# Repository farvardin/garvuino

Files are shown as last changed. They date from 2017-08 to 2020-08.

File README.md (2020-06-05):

# Garvuino 

The Garvuino is a PCB board for creating music, sounds and chiptunes, either through programming, soundtracker or live recording (midi).

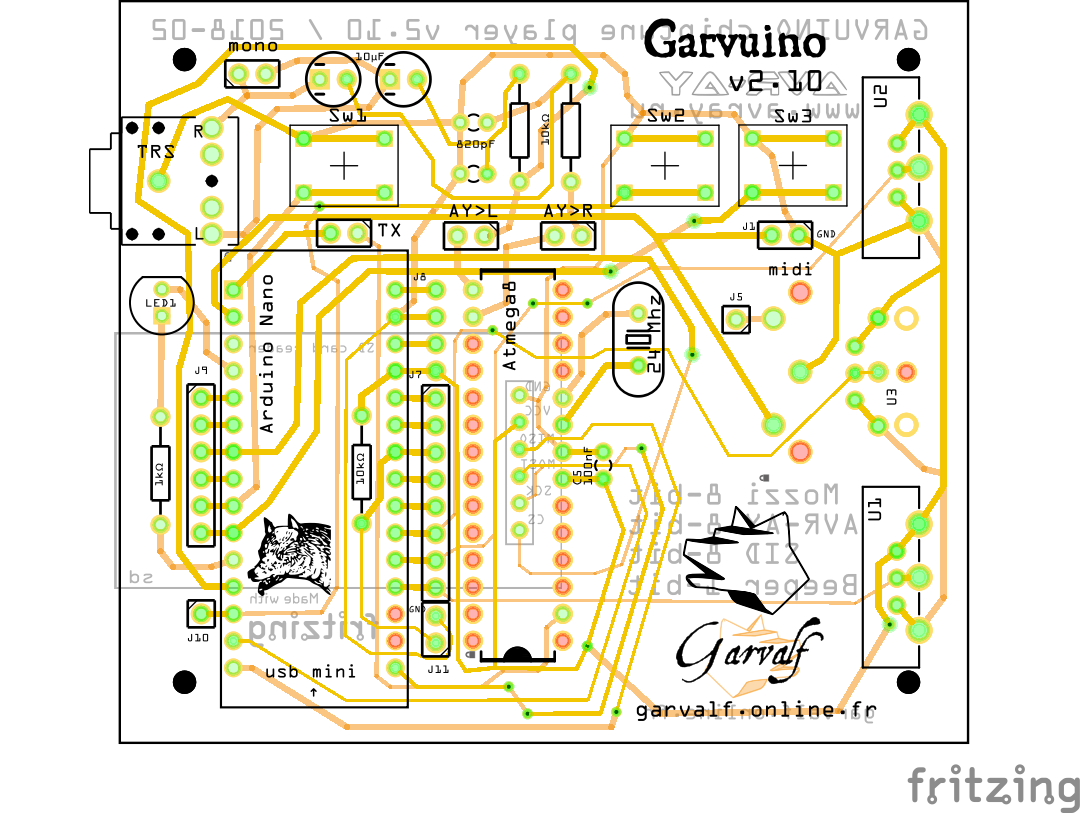
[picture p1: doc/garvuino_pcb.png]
 

It works with an Arduino Nano and an Atmega8 chip.

## Manual 

You can find the full manual [here](doc/garvuino_manual.md).

## Features 

 * AY-3-8910 emulator (using an atmega8 chip): it can replay Sinclair ZX Spectrum, Atari ST, Amstrad square wave chiptunes from the sd card.
 * Sid emulator: play some C64 musics, or use it as a midi synth with a fat sound.
 * 1-bit music: play beeper music. 
 * Mozzi synth: fun FM sounds and many other effects, driven by MIDI or some captors.

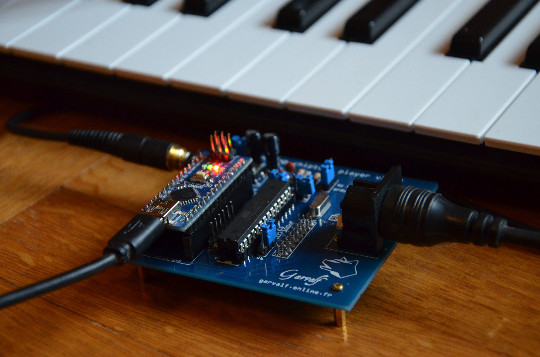
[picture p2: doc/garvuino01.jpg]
  

## How does it sound? 

### AVRAY 

 * http://picosong.com/HUGM/ (Xenon / Spectrum)
 * http://picosong.com/wseMn/ (Cauldron / Amstrad)
 * http://battleofthebits.org/arena/Entry/Underground+Water/26509/
 * https://www.youtube.com/watch?v=gzpGbokxwZ4
 * *more to come*

### Mozzi 

 * http://picosong.com/wR2RN (polydrums)
 * http://picosong.com/wR2Rr (cheap FM)
 * *more to come*

### SID emulator 

 * https://soundcloud.com/memento-somniare/sidarduino-test
 * *more to come*

### Beeper 

 * http://garvalf.online.fr/index.php?page=blog_2017-02-12
 * *more to come*

## Atmega8 setup 

Please refer to the [manual](doc/garvuino_manual.md) and [this folder](atmega8) for more info about setting up the atmega8 chip.

## PCB 

Please refer to [this folder](pcb) for the fritzing sources and gerber files.

## Breadboard 

It can also work without the PCB. Just use a breadboard and a few wires!

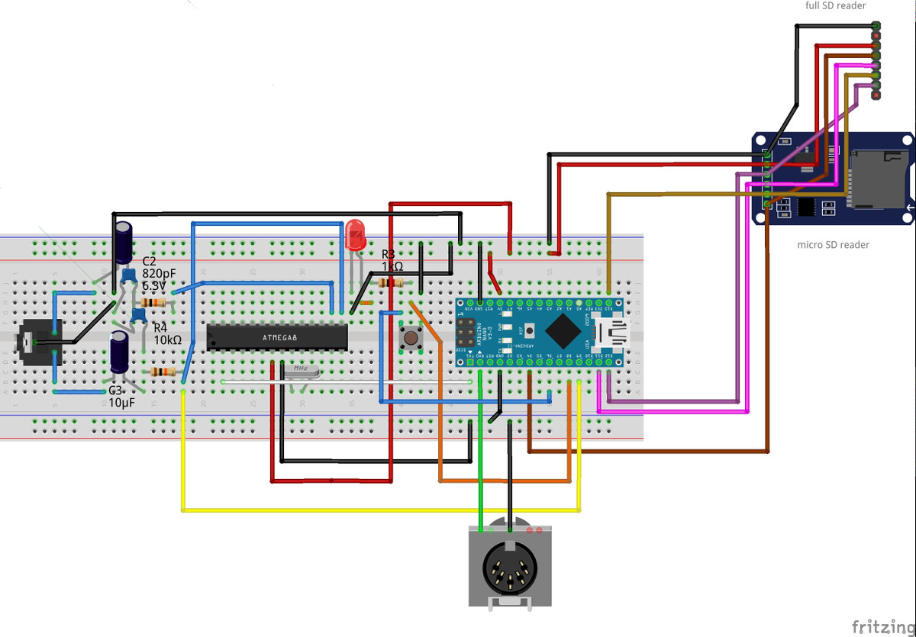
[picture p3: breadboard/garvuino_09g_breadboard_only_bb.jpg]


Please refer to [this folder](breadboard) for the fritzing sources and pdf version.

## Arduino sketches 

Get the sketches [in this folder](arduino_sketches/)

You can find [some tunes for using with the AVR-AY setup in here](tunes/). The arduino sketch can read the RSF files from the SD (it can't read the YM or AY files directly). You can convert to RSF with the [AVR-AY Player](http://www.avray.ru/avr-ay-player/).

## Links 

 * http://avray.ru/
 * http://playground.arduino.cc/Main/SID-emulator
 * http://randomflux.info/1bit/viewforum.php?id=5
 * https://sensorium.github.io/Mozzi
 * http://risgk.github.io/
 * https://github.com/dzlonline/the_synth
 * https://github.com/ArminJo/Talkie (not included in this repo, but works)

## Credits 

 * Yoruk for his help on the PCB
 * Evgeniy for AVR-AY emulator and invaluable help (initial code by Ramiros)
 * Klaud for help with avr-ay
 * Shiru for the 1-bit engines on Arduino
 * Christoph Haberer and Mario Patino for the Sid-arduino lib
 * The Mozzi team
 * Protodome for the Micro Music Macro Language (μMML) (https://github.com/protodomemusic/mmml) 

## Licence 

This BSD licence is only for the PCB sketch rendition, and code written from scratch. 
Code derived from other projects retains the original licence.
For example Avray is GPLv3.

    BSD 3-Clause License
    Copyright (c) 2015-2017, Garvalf
    All rights reserved.
    
    Redistribution and use in source and binary forms, with or without
    modification, are permitted provided that the following conditions are met:
        * Redistributions of source code must retain the above copyright
          notice, this list of conditions and the following disclaimer.
        * Redistributions in binary form must reproduce the above copyright
          notice, this list of conditions and the following disclaimer in the
          documentation and/or other materials provided with the distribution.
        * Neither the name of the <organization> nor the
          names of its contributors may be used to endorse or promote products
          derived from this software without specific prior written permission.
    
    THIS SOFTWARE IS PROVIDED BY THE COPYRIGHT HOLDERS AND CONTRIBUTORS "AS IS" AND
    ANY EXPRESS OR IMPLIED WARRANTIES, INCLUDING, BUT NOT LIMITED TO, THE IMPLIED
    WARRANTIES OF MERCHANTABILITY AND FITNESS FOR A PARTICULAR PURPOSE ARE
    DISCLAIMED. IN NO EVENT SHALL <COPYRIGHT HOLDER> BE LIABLE FOR ANY
    DIRECT, INDIRECT, INCIDENTAL, SPECIAL, EXEMPLARY, OR CONSEQUENTIAL DAMAGES
    (INCLUDING, BUT NOT LIMITED TO, PROCUREMENT OF SUBSTITUTE GOODS OR SERVICES;
    LOSS OF USE, DATA, OR PROFITS; OR BUSINESS INTERRUPTION) HOWEVER CAUSED AND
    ON ANY THEORY OF LIABILITY, WHETHER IN CONTRACT, STRICT LIABILITY, OR TORT
    (INCLUDING NEGLIGENCE OR OTHERWISE) ARISING IN ANY WAY OUT OF THE USE OF THIS
    SOFTWARE, EVEN IF ADVISED OF THE POSSIBILITY OF SUCH DAMAGE.

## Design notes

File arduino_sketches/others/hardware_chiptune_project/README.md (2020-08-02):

## Create chiptunes for the Arduino

This project is based on the "Hardware Chiptune Project" by Kryo (Linus Åkesson) : https://www.linusakesson.net/hardware/chiptune.php

It was ported to Arduino by Stimmer: 
- https://forum.arduino.cc/index.php/topic,44907.0.html

And "Bearbone" made a converter so you can create your own tunes with Kryo's original Tracker (see below):

- http://bearborne.blogspot.com/2011/12/hi-everyone-today-im-back-again-with.html
- https://www.instructables.com/id/Arduino-Chiptunes/

You can run the "kryo_hcp_org.ino" sketch, which is roughly the original port by Stimmer (and should sound close to the original tune)

The audio output is PIN 3.

## Tracker:

you can compile the sources for the tracker (on Linux), in the src folder. The "tracker" binary is provided as well (originally found in Kryo's archive)
Instructions for using the tracker can be found in README-tracker.txt

You can use my makefile to help convert the data to arduino.

The original instructions for the converter are:

- Use the tracker (Linux) to compose it.
- Export it ("%" key in the tracker).
- Run the conversion script in the tracker folder (you'll need gcc and java for it to run!).
- Open the file "song.lst" and copy its contents to the clipboard.
- Open the player sketch and replace the byte sequence in "songdata" by the sequence from "song.lst"
- Update the defines of "MAXTRACK" and "SONGLEN" to the values found in "exported.h" in the tracker directory.
- Connect a speaker to port 3 and two LEDs to ports 8 and 13 and enjoy your personal disco with synchronized light show.

Except for the "MAXTRACK" and "SONGLEN", and for connecting the speaker, the makefile should handle everything else!

For French users, you'd better switch to qwerty (done in the makefile). Non-azerty users should remove the "setxkbmap fr" in the makefile.

You can change instruments with the two keys right to the "P" key.
You can change patterns with the two keys right to the "P" key (use SHIFT in addition).
You can save your work with Ctrl+w (the key left to the "E" key)
You can export your work with % (shift+5)

More info on http://bearborne.blogspot.com/2012/02/lft-tracker-howto.html

Change your working document in the makefile, and use "make edit" to open it with the tracker, "make convert" to generate the "hardware_chiptune_project.ino" (arduino requires the .ino file to have the same name as the containing folder). "make backup" is a conveniant way to save a snapshot of your current work, in the backups folder.

Important: you might need to optimise the song (press # in the editor, shift+3) before exporting it (%), otherwise the song might not be correctly converted.

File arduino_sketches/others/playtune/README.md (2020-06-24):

## Playtune and Miditones for Arduino 

This library is an adapted version of 

 * https://github.com/LenShustek/arduino-playtune
 * https://github.com/lenshustek/miditones

They were copied and adapted for the Garvuino device:

 * https://github.com/farvardin/garvuino/

## Compile and use Miditones 

To compile miditones, just enter the "miditones" folder and type:

    make binaries

Then you can put your midifiles into this folder, edit the makefile 
(don't happend .mid at the end of the file declaration), and can type 
`make tone` to produce a .c file which you can use with playtune. 

## Playtune 

Import Playtune as a new library from your Arduino IDE.

You can use the .c file from above, or type `make ino` and it will 
provide a file you can paste or load in the Arduino IDE 
(it works great in my Arduino Uno).

## Wiring to your Arduino 

To hear the music, you have to wire a headphone or speaker to the pins 5, 6 and 9 
of your arduino (link the 3 pins together, on a breadboard for example), 
and the other end of your speaker to a ground pin. 

In addition you can add a resistor (300 or 600 ohm for ex.) to reduce some high frequencies.

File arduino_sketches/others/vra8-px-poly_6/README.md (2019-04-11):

# Digital Synth VRA8-Px v2.0.1

- 2017-07-22 ISGK Instruments
- <https://github.com/risgk/digital-synth-vra8-p/tree/vra8-px-v2>

## Concept

- 3 Voice Paraphonic Synthesizer for Arduino Uno
- A Variant of Digital Synth VRA8-P <https://github.com/risgk/digital-synth-vra8-p>

## History

### v2.0 New Features

- ORGAN Waveform Deleted, RESONANCE Steps Changed (17 -> 9)
- CC# of AMP EG, VELOCITY SENS, and CUTOFF V SENS Changed
- Improved Sound, New PRESETs, PITCH BEND Support, TRANSPOSE Support, MIDI Shield Official Support
- DETUNE S&H AMT, DETUNE EG AMT, PORTAMENTO, UNI TO MONO, CUTOFF NG AMT, EG ATTACK, AMP EG/HOLD

### v1.2 New Features

- Cutoff Velocity Sensitivity, Detune EG Amount

### v1.0 New Features

- Phase Resolution: 24 bit, Internal Signal Processing: 16 bit
- Audio Output (8 bit) with Error Diffusion, Sub Oscillators (Triangle Wave)
- Changeable Osc 2 (Detune) Level, Resonance with Q = 11.3 (Max), Velocity Sensitivity

## Features

- 3 Voice Paraphonic Synthesizer (Pseudo Polyphonic Synthesizer), MIDI Sound Module
- Serial MIDI In (38400 bps), PWM Audio Out (Pin 6), PWM Rate: 62500 Hz
    - We recommend adding a RC filter circuit to reduce PWM ripples
    - A cutoff frequency 10.6 kHz (R: 150 ohm, C: 100 nF) works well
    - A cutoff frequency 15.9 kHz (R: 100 ohm, C: 100 nF) works well, too
    - **CAUTION**: Click sounds may occur when you connect the audio out to an amp/a speaker or reset the board
    - **CAUTION**: The Arduino PWM audio output is a unipolar LINE OUT
        - Please connect this to a power amp/a headphone amp (not to a speaker/a headphone directly)
- Sampling Rate: 15625 Hz, Bit Depth: 8 bit, LPF Attenuation Slope: -12 dB/oct
- Recommending [Hairless MIDI<->Serial Bridge](http://projectgus.github.io/hairless-midiserial/) to connect PC
- Files
    - `DigitalSynthVRA8Px.ino` is a sketch for Arduino/Genuino Uno
    - `make-sample-wav-file.cc` is for Debugging on PC
        - Requiring GCC (G++) or other
        - `make-sample-wav-file-cc.bat` makes a sample WAV file (working on Windows)
    - `generate-*.rb` generate source files
        - Requiring a Ruby execution environment
- **CAUTION**: We recommend Arduino IDE 1.8.3

## VRA8-Px CTRL

- Parameter Editor (MIDI Controller) for VRA8-Px, Web App
- We recommend Google Chrome, which implements Web MIDI API
- VRA8-Px CTRL includes PRESET programs
- Recommending [loopMIDI](http://www.tobias-erichsen.de/software/loopmidi.html) (virtual loopback MIDI cable) to connect VRA8-Px
- **CAUTION**: Low CUTOFF with high RESONANCE can damage the speakers

## Controllers

    +----------------+------+----------------+---------------+----------------+------------------------------+
    | Controller     | INIT | Value 0        | Value 64      | Value 127      | Notes                        |
    +----------------+------+----------------+---------------+----------------+------------------------------+
    | UNISON/MIX     | 0    | OFF            | ON            | ON             | 3 Voice UNISON               |
    |                |      | +70.7%/+70.7%  | +70.7%/-70.7% | +70.7%/+70.7%  | Main/DETUNE MIX Level        |
    | WAVEFORM/SUB   | 0    | SAWtooth       | SQuare        | SQuare         | WAVEFORM                     |
    |                |      | 100%           | 0%            | 100%           | SUB Osc Level                |
    | DETUNE         | 48   | 0.06 Hz        | 1.0 Hz        | 3.8 Hz         |                              |
    | DETUNE S&H AMT | 32   | Avg. 0         | Avg. +32      | Avg. +63.5     | S&H: 488.3 Hz (Red Noise)    |
    | DETUNE EG AMT  | 48   | -126 (EG 100%) | 0             | +125 (EG 100%) | Modulates DETUNE             |
    | PORTAMENTO     | 32   | Off            | 0.09 s/Oct    | 0.8 s/Oct      | PORTAMENTO Time              |
    | UNI TO MONO    | 0    | OFF            | ON            | ON             | Change UNISON => MONO        |
    +----------------+------+----------------+---------------+----------------+------------------------------+
    | CUTOFF         | 64   | 0.22 kHz (A3)  | 1.2 kHz       | 7.04 kHz (A8)  | Range: 4 to 124              |
    | RESONANCE      | 64   | Q = 0.7        | Q = 2.8       | Q = 11.3       | 9 steps                      |
    | CUTOFF EG AMT  | 96   | -126 (EG 100%) | 0             | +125 (EG 100%) | EnvGen Modulates CUTOFF      |
    | CUTOFF NG AMT  | 64   | Avg. -32       | 0             | Avg. +31       | NoiseGen (White) Mods CUTOFF |
    +----------------+------+----------------+---------------+----------------+------------------------------+
    | EG ATTACK      | 0    | 4 ms           | 60 ms         | 4.2 s          | EnvGen ATTACK Time           |
    | EG DECAY       | 64   | 34 ms          | 2.2 s         | Infinity       | EnvGen DECAY Time            |
    | AMP EG/HOLD    | 0    | AMP EG OFF     | AMP EG ON     | AMP EG ON      | AMP EG ON: 64-127            |
    |                |      | HOLD OFF       | HOLD ON       | HOLD OFF       | HOLD ON: 32-95               |
    +----------------+------+----------------+---------------+----------------+------------------------------+
    | VELOCITY SENS  | 0    | 0%             | 50.4%         | 100%           | Gain VELOCITY SENSitivity    |
    | CUTOFF V SENS  | 127  | -128 (V 127)   | 0 (V 127)     | +126 (V 127)   | CUTOFF Velocity SENSitivity  |
    +----------------+------+----------------+---------------+----------------+------------------------------+

## MIDI Implementation Chart

      [Paraphonic Synthesizer]                                        Date: 2017-07-22       
      Model: Digital Synth VRA8-Px    MIDI Implementation Chart       Version: 2.0.1         
    +-------------------------------+---------------+---------------+-----------------------+
    | Function...                   | Transmitted   | Recognized    | Remarks               |
    +-------------------------------+---------------+---------------+-----------------------+
    | Basic        Default          | x             | 1             |                       |
    | Channel      Changed          | x             | x             |                       |
    +-------------------------------+---------------+---------------+-----------------------+
    | Mode         Default          | x             | Mode 3        |                       |
    |              Messages         | x             | x             |                       |
    |              Altered          | ************* |               |                       |
    +-------------------------------+---------------+---------------+-----------------------+
    | Note                          | x             | 0-127         |                       |
    | Number       : True Voice     | ************* | 24-84         | (w/o TRANSPOSE)       |
    +-------------------------------+---------------+---------------+-----------------------+
    | Velocity     Note ON          | x             | o (V=1-127)   |                       |
    |              Note OFF         | x             | x             |                       |
    +-------------------------------+---------------+---------------+-----------------------+
    | After        Key's            | x             | x             |                       |
    | Touch        Ch's             | x             | x             |                       |
    +-------------------------------+---------------+---------------+-----------------------+
    | Pitch Bend                    | x             | o             | Range: 2 (or 12)      |
    +-------------------------------+---------------+---------------+-----------------------+
    | Control                    16 | x             | o             | UNISON/MIX            |
    | Change                     17 | x             | o             | WAVEFORM/SUB          |
    |                            18 | x             | o             | DETUNE                |
    |                            19 | x             | o             | CUTOFF NG AMT         |
    |                            20 | x             | o             | CUTOFF                |
    |                            21 | x             | o             | RESONANCE             |
    |                            22 | x             | o             | CUTOFF EG AMT         |
    |                            23 | x             | o             | EG DECAY              |
    |                            24 | x             | o             | EG ATTACK             |
    |                            25 | x             | o             | DETUNE S&H AMT        |
    |                            26 | x             | o             | DETUNE EG AMT         |
    |                            27 | x             | o             | AMP EG/HOLD           |
    |                            28 | x             | o             | VELOCITY SENS         |
    |                            29 | x             | o             | CUTOFF V SENS         |
    |                            30 | x             | o             | PORTAMENTO            |
    |                            31 | x             | o             | UNI TO MONO           |
    +-------------------------------+---------------+---------------+-----------------------+
    | Program                       | x             | x             |                       |
    | Change       : True #         | ************* |               |                       |
    +-------------------------------+---------------+---------------+-----------------------+
    | System Exclusive              | x             | x             |                       |
    +-------------------------------+---------------+---------------+-----------------------+
    | System       : Song Pos       | x             | x             |                       |
    | Common       : Song Sel       | x             | x             |                       |
    |              : Tune           | x             | x             |                       |
    +-------------------------------+---------------+---------------+-----------------------+
    | System       : Clock          | x             | x             |                       |
    | Real Time    : Commands       | x             | x             |                       |
    +-------------------------------+---------------+---------------+-----------------------+
    | Aux          : Local ON/OFF   | x             | x             |                       |
    | Messages     : All Notes OFF  | x             | o (123-127)   |                       |
    |              : Active Sense   | x             | x             |                       |
    |              : Reset          | x             | x             |                       |
    +-------------------------------+---------------+---------------+-----------------------+
    | Notes                         |                                                       |
    |                               |                                                       |
    +-------------------------------+-------------------------------------------------------+
      Mode 1: Omni On,  Poly          Mode 2: Omni On,  Mono          o: Yes                 
      Mode 3: Omni Off, Poly          Mode 4: Omni Off, Mono          x: No

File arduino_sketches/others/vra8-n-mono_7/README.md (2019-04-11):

# Digital Synth VRA8-N v2.0.1

- 2019-03-24 ISGK Instruments
- <https://github.com/risgk/digital-synth-vra8-n>

## Concept

- Monophonic Synthesizer (MIDI Sound Module) for Arduino Uno

## Change History

- v2.0.1
    - Fix sound quality degradation in v2.0.0
    - Revert "SUSTAIN (OFF/ON)" to "SUSTAIN"
- v2.0.0 (Major Changes)
    - Change "OSC (SAW/SQ)" to "OSC1/2 (SAW/SQ)"
    - Add "EXPRESSION", "EXP > CUTOFF", "EXP > AMP LEVEL", and "EXP BY VEL (OFF/ON)"
- v1.2.1
    - Improve sound quality
    - Improve VRA8-N CTRL compatibility between versions
- v1.2.0 (Major Changes)
    - Add "EG > PITCH(-/+)", "EG > P. TGT (1&2/2)", "RELEASE (OFF/ON)", and "EG > LFO RATE (-/+)"
    - Change "OSC2 MIX" (OSC2 Max 50%) to "OSC MIX (1/2)" (OSC2 Max 100%)
    - Change "SUB WAVE (SIN/SQ)" to "SUB (SIN/NOISE/SQ)"
    - Change "AMP (GATE+RLS/EG)" to "AMP EG (OFF/ON)" (No Release)
    - Change "SUSTAIN" to "SUSTAIN (OFF/ON)"
    - Change "LFO WAVE (TRI/SQ)" to "LFO (T/2/SA/RND/SQ)"
    - Change "LFO > PITCH (2/1+2)" to "LFO > PITCH (-/+)" and "LFO > P. TGT (1&2/2)"
    - Change "KEY ASGN (LO/LAST)" to "K. ASN (L/L/P/H/LST)"
    - Change the variation range of "CUTOFF" 7-127 to 4-124
    - Change the names of controllers
    - Change the layout and the display of VRA8-N CTRL
    - Change PRESETs
- v1.1.0 (Major Changes)
    - Add "SUB WAVE (SIN/SQ)" and "LFO WAVE (TRI/SQ)"

## Features

- Sampling Rate: 31.25 kHz, Bit Depth: 8 bit, LPF Attenuation Slope: -12 dB/oct
- Serial MIDI In (38.4 kbps), PWM Audio Out (Pin 6), PWM Rate: 62.5 kHz
    - We recommend adding a RC filter circuit to reduce PWM ripples
        - A cutoff frequency 15.9 kHz (R: 100 ohm, C: 100 nF) works well
    - **CAUTION**: The Arduino PWM audio output is a unipolar Line Out
        - Please connect this to a power amp/a headphone amp (not to a speaker/a headphone directly)
    - **CAUTION**: Click sounds may occur when you connect the audio out to an amp or reset the board
- We recommend [Hairless MIDI<->Serial Bridge](http://projectgus.github.io/hairless-midiserial/) to connect PC
    - A MIDI Shield (MIDI Breakout) and a power supply adapter are desirable to avoiding USB noise
        - Edit `SERIAL_SPEED` in `DigitalSynthVRA8N.ino` to use MIDI Shield
- Files
    - `DigitalSynthVRA8N.ino` is a sketch for Arduino (Genuino) Uno Rev3
    - `make-sample-wav-file.cc` is for Debugging on PC
        - Requiring GCC (g++) or other
        - `make-sample-wav-file-cc.bat` makes a sample WAV file (working on Windows)
    - `generate-*.rb` generates source files
        - Requiring a Ruby execution environment
- **CAUTION**: We *strongly recommend* **Arduino IDE 1.8.5**
    - `DigitalSynthVRA8N.ino` *does not work well* with Arduino IDE 1.8.6 or later

## VRA8-N CTRL

- MIDI Controller (Editor) for VRA8-N, Web App
- VRA8-N CTRL converts Program Changes (#0-7 for PRESET) into Control Changes
- VRA8-N CTRL memorizes USER Programs (#8-15)
- We recommend Google Chrome, which implements Web MIDI API
- We recommend [loopMIDI](http://www.tobias-erichsen.de/software/loopmidi.html) (virtual loopback MIDI cable) to connect VRA8-N
- **CAUTION**: Low CUTOFF with high RESONANCE can damage the speakers
- **CAUTION**: Click sounds may occur when you change the control values

## Details of Controllers

- "OSC1/2 (SAW/SQ)": OSC1 Wave / OSC2 Wave
    - Values 0-15: OSC1 SAW / OSC2 SAW
    - Values 16-63: OSC1 SAW / OSC2 SQUARE
    - Values 64-111: OSC1 SQUARE / OSC2 SAW
    - Values 112-127: OSC1 SQUARE / OSC2 SQUARE
- "SUB (SIN/NOISE/SQ)": SUB Osc Wave
    - Values 0-31: SIN
    - Values 32-95: NOISE
    - Values 96-127: SQUARE
- "LFO (T/2/SA/S&H/SQ)": LFO Wave
    - Values 0-15: Triangle (Key Trigger: Off)
    - Values 16-47: Triangle 2 (Key Trigger: On)
    - Values 48-79: SAW Down (Key Trigger: On)
    - Values 80-111: RANDOM (Key Trigger: On)
    - Values 112-127: SQUARE Up (Key Trigger: On)
- "LEGATO (OFF/ON)": LEGATO Portamento
    - When LEGATO Portamento is ON, Single Trigger is forced
- "K. ASN (L/L/P/H/LST)": Key ASSIGN / Trigger Mode
    - Values 0-47: Lowest Note / Single Trigger
    - Values 48-79: Paraphonic (Lowest and Highest Notes) / Single Trigger
    - Values 80-111: Highest Note / Single Trigger
    - Values 112-127: LAST One Note / Multi Trigger
- "EXP BY VEL (OFF/ON)": EXPRESSION Control By (Note ON) VELOCITY

## A Sample Setting of a Physical Controller (8-Knob)

    +-------------------+---------------+---------------+---------------+
    | CC #16            | CC #17        | CC #23        | CC #19        |
    | CUTOFF            | RESONANCE     | ATTACK        | DECAY         |
    +-------------------+---------------+---------------+---------------+
    | CC #24            | CC #25        | CC #26        | CC #22        |
    | OSC (SAW/SQ)      | OSC MIX (1/2) | SUB LEVEL     | PORTAMENTO    |
    +-------------------+---------------+---------------+---------------+

## MIDI Implementation Chart

      [Monophonic Synthesizer]                                        Date: 2019-03-24       
      Model: Digital Synth VRA8-N     MIDI Implementation Chart       Version: 2.0.1         
    +-------------------------------+---------------+---------------+-----------------------+
    | Function...                   | Transmitted   | Recognized    | Remarks               |
    +-------------------------------+---------------+---------------+-----------------------+
    | Basic        Default          | x             | 1             |                       |
    | Channel      Changed          | x             | x             |                       |
    +-------------------------------+---------------+---------------+-----------------------+
    | Mode         Default          | x             | 3             |                       |
    |              Messages         | x             | x             |                       |
    |              Altered          | ************* |               |                       |
    +-------------------------------+---------------+---------------+-----------------------+
    | Note                          | x             | 0-127         |                       |
    | Number       : True Voice     | ************* | 0-120         |                       |
    +-------------------------------+---------------+---------------+-----------------------+
    | Velocity     Note ON          | x             | o (V=1-127)   | When EXP BY VEL is ON |
    |              Note OFF         | x             | x             |                       |
    +-------------------------------+---------------+---------------+-----------------------+
    | After        Key's            | x             | x             |                       |
    | Touch        Ch's             | x             | x             |                       |
    +-------------------------------+---------------+---------------+-----------------------+
    | Pitch Bend                    | x             | o             |                       |
    +-------------------------------+---------------+---------------+-----------------------+
    | Control                     1 | x             | o             | MODULATION DEPTH      |
    | Change                     11 | x             | o             | EXPRESSION            |
    |                               |               |               |                       |
    |                            24 | x             | o             | OSC1/2 (SAW/SQ)       |
    |                            25 | x             | o             | OSC MIX (1/2)         |
    |                            20 | x             | o             | OSC2 COARSE (-/+)     |
    |                            21 | x             | o             | OSC2 FINE (-/+)       |
    |                               |               |               |                       |
    |                            29 | x             | o             | SUB (SIN/NOISE/SQ)    |
    |                            26 | x             | o             | SUB LEVEL             |
    |                           104 | x             | o             | EG > PITCH (-/+)      |
    |                           105 | x             | o             | EG > P. TGT (1&2/2)   |
    |                               |               |               |                       |
    |                            16 | x             | o             | CUTOFF                |
    |                            17 | x             | o             | RESONANCE             |
    |                            18 | x             | o             | EG > CUTOFF (-/+)     |
    |                            31 | x             | o             | AMP EG (OFF/ON)       |
    |                               |               |               |                       |
    |                            23 | x             | o             | ATTACK                |
    |                            19 | x             | o             | DECAY                 |
    |                            27 | x             | o             | SUSTAIN               |
    |                            28 | x             | o             | RELEASE (OFF/ON)      |
    |                               |               |               |                       |
    |                            14 | x             | o             | LFO (T/2/SA/RND/SQ)   |
    |                            80 | x             | o             | LFO RATE              |
    |                            82 | x             | o             | LFO > PITCH (-/+)     |
    |                            83 | x             | o             | LFO > CUTOFF (-/+)    |
    |                               |               |               |                       |
    |                            81 | x             | o             | LFO DEPTH             |
    |                             3 | x             | o             | EG > LFO RATE (-/+)   |
    |                             9 | x             | o             | LFO > P. TGT (1&2/2)  |
    |                            15 | x             | x             | (RESERVED)            |
    |                               |               |               |                       |
    |                            85 | x             | o             | P. BEND RANGE         |
    |                            86 | x             | x             | (RESERVED)            |
    |                           106 | x             | o             | EXP > CUTOFF (-/+)    |
    |                           107 | x             | o             | EXP > AMP LEVEL       |
    |                               |               |               |                       |
    |                            22 | x             | o             | PORTAMENTO            |
    |                            30 | x             | o             | LEGATO (OFF/ON)       |
    |                            87 | x             | o             | K. ASN (L/L/P/H/LST)  |
    |                            89 | x             | o             | EXP BY VEL (OFF/ON)   |
    +-------------------------------+---------------+---------------+-----------------------+
    | Program                       | x             | o             |                       |
    | Change       : True #         | ************* | 0-7           |                       |
    +-------------------------------+---------------+---------------+-----------------------+
    | System Exclusive              | x             | x             |                       |
    +-------------------------------+---------------+---------------+-----------------------+
    | System       : Song Pos       | x             | x             |                       |
    | Common       : Song Sel       | x             | x             |                       |
    |              : Tune           | x             | x             |                       |
    +-------------------------------+---------------+---------------+-----------------------+
    | System       : Clock          | x             | x             |                       |
    | Real Time    : Commands       | x             | x             |                       |
    +-------------------------------+---------------+---------------+-----------------------+
    | Aux          : Local ON/OFF   | x             | x             |                       |
    | Messages     : All Notes OFF  | x             | o 123-127     |                       |
    |              : Active Sense   | x             | x             |                       |
    |              : Reset          | x             | x             |                       |
    +-------------------------------+---------------+---------------+-----------------------+
    | Notes                         |                                                       |
    |                               |                                                       |
    +-------------------------------+-------------------------------------------------------+
      Mode 1: Omni On,  Poly          Mode 2: Omni On,  Mono          o: Yes                 
      Mode 3: Omni Off, Poly          Mode 4: Omni Off, Mono          x: No

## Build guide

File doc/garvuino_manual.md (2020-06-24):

# Garvuino manual

Thank you for your interest in Garvuino! The Garvuino is a PCB board for creating music, sounds and chiptunes, either through programming, soundtracker or live recording (midi).

As the hardware is open-source, you can modify, hack and have fun with it without restriction.

The PCB, schematics, code and further instructions can be found on https://github.com/farvardin/garvuino/

  

## Presentation of the board 

Several modes can be used: 

### AY-3-8910 emulator 

On Atmega8 chip, driven by the Arduino nano, from the [AVR-AY project](http://avray.ru/)

 * It can replay Sinclair ZX Spectrum, Atari ST, Amstrad chiptunes from the sd card. You can create thoses chiptunes with Vortex Tracker II or Arkos Tracker.
 * It's possible to use it as a (very simple and dirty) AY soundbox, driven by some external captors (light sensor). But it might not be possible to controle it with MIDI.

### Sid emulator 

On Arduino, from the [sid emulator lib](http://playground.arduino.cc/Main/SID-emulator)

 * It can replay some sid files, from the arduino memory, which is limited (so tunes will be cut). We'd like to find a way to stream the tune from the sd card, it's probably possible.
 * It can be used as a Sid synth, driven by midi.

### 1-bit music 

From various 1-bit engines: http://randomflux.info/1bit/viewforum.php?id=5 (on arduino)

 * It can play music from the arduino memory. 1-bit music don't need much memory so a whole song, even a complex one, can fit in the memory. You can create those songs with Beepola or MilkyTracker.
 * It might be possible to stream data from SD if the 1-bit music engine chosen is the same for all the songs.
 * It might be possible to create a 1-bit synth in the future. Probably not an easy task.

### Mozzi synth 

 * [Mozzy synth](https://sensorium.github.io/Mozzi), can output fun FM sounds and many other effects.

### Hardware 

The board has 2 chips : 

 * an Arduino Nano for the compute (it is a complete board for development)
 * an optional Atmega8 for AY sound output.

A few components :
 * a 24 Mhz crystal that is driving the Atmega8
 * some capacitors and resistors to filter the output 
 * a SD card reader to read AY music files (optional)
 * a DIN5 midi input to use the board as a midi synth (optional)  



The LED is connected to D8 on Arduino. The audio output to D9. The switch to D6. On Garvuino v2.10 and expansion board, the potentiometers are connected to A0 to A1 and to A0 to A4 respectively.

More precisely:

| PIN |use|
|---------------|
|D2 |FREE|
|D3 |audio out (some sketches)|
|D4 |CS for SD card reader|
|D5 |FREE|
|D6 |switch Sw1 / audio out (some sketches)|
|D7 |switch Sw3 / audio out (playtune)||
|D8 |led1|
|D9 |audio out (most sketches)|
|D10 |switch Sw2|
|D11 |MOSI: SD card reader|
|D12 |MISO: SD card reader|
|D13 |SCK; SD card reader (onboard LED too)||
|A0 |POT 1|
|A1 |POT 2|
|A2 |POT 3|
|A3 |POT 4|
|A4 |SDA: oled display|
|A5 |SCL: oled display|
|A6 |POT 5|
|A7 |FREE|

(TODO: playtune outputs to PIN9, 5 and 6)

There are a few jumpers on the board. They are for switching between some modes.

When used in AY mode, the mono jumper should be off, when used in beeper, sid or mozzi mode the mono jumper should be on, the J4 (ay chip ground, v1.09 board only) should be off. Also the AY>L and AY>R can be off to reduce noise (but it will work anyway). And TX could be off as well when flashing the arduino chip (you can leave it on, but if the transfer fails, try to remove it)

More detailled informations about the jumpers:

 * mono: used in mozzi, 1-bit and sid mode. You can remove the jumper in AY mode because it's in stereo (but you might also prefer using the mono mode)

 * TX: used for transmitting data to the Atmega8 chip in AY mode. You can remove the jumper when not in AY mode. You can also keep it, it doesn't matter, unless you have some problem for flashing the arduino board. On some boards, the jumper is below the board for easier access to the push button.

 * AY>L and AY>R: used in AY mode. You can cut a voice if you remove the jumper. If you remove the jumper when not in AY mode, you'll be sure there won't be extra noise from the Atmega8 chip.

 * J1: extra midi input GND (below) and midi wire nb 5 if you don't want to use the DIN5 plug.

 * J2/J3: for connecting regular (big) SD reader. Most board will use the smaller SD reader

 * J4 / ay chip GND / arduino chip (v1.09 board only): ay chip used in AY mode. It's better to put the jumper in the "arduino chip" mode (bottom), when not using AY otherwise you'll get extra and residual noise from the atmega8 chip.

 * J5 (v1.09 board only): not used. Linked to midi 4 wire "just in case".

 * J6 (v1.09 board only): not used. Could be used to switch off the atmega8 but since there are still some residual noise without it, it can be kept connected. It's been soldered on most boards.

 * J7 (v1.09) / J11 (v2.10): can be used for programming the Arduino for Analog input (potentiomer, light sensor for example)

 * J8: not used. Can be connected to arduino +5V, RST, GND and VIN but shouldn't be necessary.

 * J9: can be used for programming the Arduino for digital output (more leds for example) 

 * J10: not used. Extra digital output.

 * Led: for monitoring some infos

You can of course connect audio out to the mini-jack, but it's also possible to connect a small buzzer (HP), for example 8 ohms / 1 W to the AY>L (under the L) and to the GND (for example in the middle 3-pin J4 or on the GND of J1, if it's installed) then you'll get very cheap sound. It can be useful for monitoring.

```
Midi: You can plug a DIN5 midi cable into the dedicated port. When removing it, please do it slowly, to avoid tearing everything apart. And when pluging it in and out, hold the midi port with your hand to avoid extra pressure on the connexions.
```

You can also use [hairless midi serial bridge](https://projectgus.github.io/hairless-midiserial/) (windows, mac os x, linux) or [ttymidi](http://www.varal.org/ttymidi/) (linux) to create a virtual connection going through serial port. You'll need to adjust the arduino sketch to enable this (search for hairless midi or ttymidi in the sketch, or for #define USBMIDI at the begining of the sketch).

## Flashing the Garvuino board 

This board is supposed to work extensively with the Arduino IDE (http://arduino.cc/). You must download it and use it for developping, changing sounds and engines. The only exception is if you only intend to use the board as a AY player, then you can just change the tunes on the SD card.

Programs on Arduino are called sketches. Most sketches are tested with Arduino IDE 1.8.# but they should work with IDE 1.6.#. With latest arduino IDE (1.8.9), you must select: Processor: "Atmega328 (old bootloader)".

Get the sketches from there:

https://github.com/farvardin/garvuino/archive/master.zip

For flashing, just launch the Arduino IDE, connect the arduino to your computer using an USB mini cable, select in the tools>arduino nano, atmega328(P)(old bootloader, if applicable), select the right port. 

Load a sketch from the arduino_sketches/ folder.

For flashing, you need to unplug the midi cable from your synth ir garvuino if it's connected, or powerdown the synth. If you want to develop a sketch on garvuino, it can be tiresome to always unplug the midi. You can use a simpler wire <=> midi connected to the J1, with GND to midi GND (pin 2) and the other slot (which is connected to the RXD port) to the midi pin 5, this way it's faster to unplug. Or use ttymidi or hairless midi serial to usb port (see above)

In the case you get a:

    avrdude: stk500_getsync() attempt 1 of 10: not in sync: resp=0x32

it can be from different causes. If the midi plug is connected, see advice above. But it can also appear at random occasions. I suspect it's because of some electricity in the atmega8 chip. In this case, you can remove the TX jumper (above the arduino nano). You only need it connected when playing AY chiptunes (see below).
This kind of message can also be seen if you've choosen the wrong port to connect the arduino.

### Flashing for AY music 

Just load avray/avray_sd_sketch/avray_sd_sketch.ino, put some tunes from tunes/aym_tunes/1_75MHz/rsf/ into your SD card and power the device!

If you create your own tunes (using Vortex Tracker II for example), you'll need to convert them to RSF using the AVR-AY player: http://www.avray.ru/avr-ay-player/

You can also create tunes using [Deflemask](http://deflemask.com/) (choose Master System SN76489 PSG) or [Bamboo Tracker](https://github.com/rerrahkr/BambooTracker/) (use only the SSC channels) and convert the exported VGM tunes to RSF using the vgm2rsf tool: https://github.com/farvardin/garvuino/tree/master/tools/vgm2rsf

### Sid emulator 

load /sid/sid_midi/sid_midi.ino for the Sid emulator synth. Change sound mode with the switch. You can change some sound with knobs on your keyboard. The sketch is programmed for my Behringer UMA25S keyboard, knob E09 to E13 (midi control 71 to 75).

There is also a sid player (/sid/sid_player/) which can load some SID data and play it from the arduino (at the moment it can only load from memory, which isn't big enough for a complete song).

You can also connect a gyroscope module to the Garvuino and have fun with sounds. See sid/gyro_header_sid/ for this.

### Flashing for 1-bit music 

Only one 1-bit music can be installed into the Arduino at a time. Load a sketch, for example beeper/arduino_qchan/arduino_qchan.ino and flash the Arduino. Music should go out of the mini-jack now!

You can compose music using the [beepola tracker](http://freestuff.grok.co.uk/beepola/).

Beepola can use the Tritone, Qchan and Phaser1 engines. 

There are python converters in the folder to convert your own music to arduino code. Just make it into beepola and "compile" it to .bin format in the tools menu (without song engine, "song data only"). Convert the bin to data readable by the arduino with the python script. 

Then include your code into the arduino sketch (use #include "your_song.h" instead of #include "music_data.h" for example.) Use the line that is not commented (a comment on arduino starts with with two /)

For the octode engine, you'll have to edit a .xm file with a tracker like milkytracker. See http://battleofthebits.org/lyceum/View/Octode for more informations. There is a xm to arduino converter in the arduino_octode folder as well.

Read more on the [1-bit forum thread](http://randomflux.info/1bit/viewforum.php?id=5) (search for arduino)

If you have some problem for creating your own music and exporting it to arduino, you can join the 1-bit forum to request for help.

### Flashing for Mozzi synth 

There are several examples in the mozzi/ folder, just try them out!

You can also use most mozzi examples from the original library (see Examples/Mozzi in the Arduino IDE).

### Flashing other sketches 

The Garvuino should be able to play many other sketches from various projects on internet.

#### Playtune 

Playtune can play some MIDI files after converting them. It can be found in ./arduino_sketches/others/playtune

Just connect PIN 5 to AY>L and PIN 6 to AY>R (PIN 9 is already connected to audio output) and you'll get a midi player able to play up to 3 voices. You can connect even more voices to the free Digital Output on the Garvuino (for example by adding a pin on PIN 7).

Use the playtune_nano/playtune_nano.ino sketch.

#### Auduino 

The Auduino is a project for using granular synthesis with 5 potentiometers, you'll have to connect PIN3 from the arduino to the AY>L audio output (read the sketch header for more informations).

#### "The Synth" 

"The Synth" is a project for using Arduino as a monophonic wavetables synth. 
It's lightweight and easy to hack.

You'll have to connect PIN3 from the arduino to the AY>L audio output (read the sketch header for more informations).

https://www.instructables.com/id/Turn-your-Arduino-into-a-4-voice-wavetable-synth-w/

#### Digital Synth VRA8 

VRA8 is an awesome project with several different monophonic and polyphonic synths for Arduino.

It's compatible with the Garvuino. Get more informations for how to use it on http://risgk.github.io/.

You'll have to connect PIN6 from the arduino to the AY>L audio output.

https://www.instructables.com/id/Digital-Synth-VRA8-Px-for-Arduino-Uno/

For hairless midi, get it on https://projectgus.github.io/hairless-midiserial/

On Debian based systems, to run it, you'll probably need to install libsm6, libxrender, libasound2 and libasound2-plugins (for i386):

    sudo apt install libsm6:i386 libxrender1:i386 libasound2:i386 libasound2-plugins:i386

Run the arduino sketch (using the 1.8.5 or below IDE for example). Close Arduino IDE.

Start Hairless MIDI. In prefs, change Baud rate to 38400.
Select "Serial Port": USB-serial adapter.

Start virtual midi port with:

    sudo modprobe snd-virmidi

In hairless midi window, select a virtual Raw midi port in Midi Out. Then, in Midi In, "serial->Midi" should appear.

Visit http://risgk.github.io/digital-synth-vra8-px/vra8-px-ctrl.html with Chrome (or Chromium). Select RtMidi input in the web page (in the MIDI OUT list).

Now you should get some sounds from this wonderful synth.

In the case you need to reflash the Arduino, just uncheck the "serial<->midi bridge on" button in Hairless midi, and check it again to transmit midi.

#### MMML 

Micro Music Macro Language (μMML) (https://github.com/protodomemusic/mmml) is using AVR programming to flash Atmega chips (Attiny85, Atmega168...). It works too with the Atmega8 found on the Garvuino!

To make it work, you'll have to reflash the firmware of the atmega8 (or get another chip) using an USBasp. You can learn more about this in the "Atmega8 setup and flashing" section of this manual.

And to use the arduino as a power supply, just remove the arduino chip from its socket, connect the 5V from the arduino to the PIN 7 on the atmega8, connect arduino GND to atmega8 PIN 8, connect a passive speaker to atmega8 PIN 22 (another GND) and to atmega8 PIN 14 (PB0)

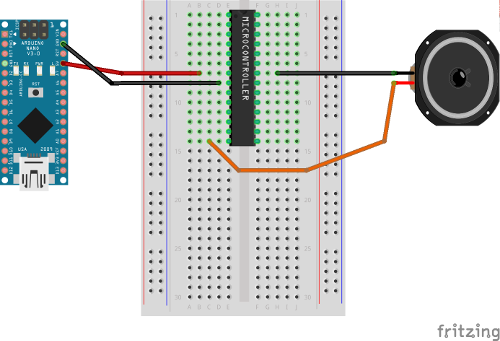
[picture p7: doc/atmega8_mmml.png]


You can also use the Garvuino as an audio output, instead of the speaker, just connect PIN 14 to the empty arduino socket, in the D9 hole (4th from the bottom left), and PIN 22 to the GND hole (2nd from the top right)

## Assemble the Garvuino board 

If you got the board through a kit, soldering it should be pretty simple as there are only basic components. 

If you have no clue about soldering, this guide might be of some use for you: https://www.makerspaces.com/how-to-solder/

Solder the resistors and capacitors first for example, then the jumpers, socket, led, switch, crystal and audio jack. In any case, the regular sd card reader should be soldered after all of this.

If you use a micro-sd reader, it could be better to solder first the left socket for the atmega8 chip (by side of the arduino chip), then the other elements (led, resistor, pins), then the micro-sd reader, then the right part of the socket for the atmega8 chip, otherwise it's more difficult to solder the micro-sd reader, yet still possible.

There is a little error on the version 1.09 / 2017-08 of the PCB board, which I've fixed with a wire. On this version, the D6 output on arduino is shared with the LED so it might not always be available on some sketches.

### Bill of Materials 

    Name                            nb    (optional part)
    		
    Garvuino PCB                     1	
    crystal 24 mhz                   1	
    arduino nano                     1	
    atmega8                          1	
    ceramic capacitor 820 pF         2	
    electrolytic capac. 10 uF        2	
    ceramic capacitor 100 nF         1       x
    led                              1       x
    DIN5 connector (midi)            1       x
    1 kΩ Resistor                    1       x
    10 kΩ Resistor                   2	
    micro sd module                  1	
    momentary switch (6x6mm type)    1
    audio jack 3.5 mm (TRS)          1	
    jumper                           6	
    female header socket PCB 2.54mm  1
    male pin strips 2.54             1
    female pin strips 2.54           1

### Atmega8 setup and flashing 

If you've bought the Garvuino assembled or in a kit, the atmega8 is already flashed for AY emulation. Yet, you might want to install a new revision of the AVRAY program, and use different speed and settings. Here are the instructions:

Get a "USBASP USB ISP Programmer & 10 Pin ISP interface Cable - AVR ATMEL ATMega".

Connect it according to this schematic for the atmega8:

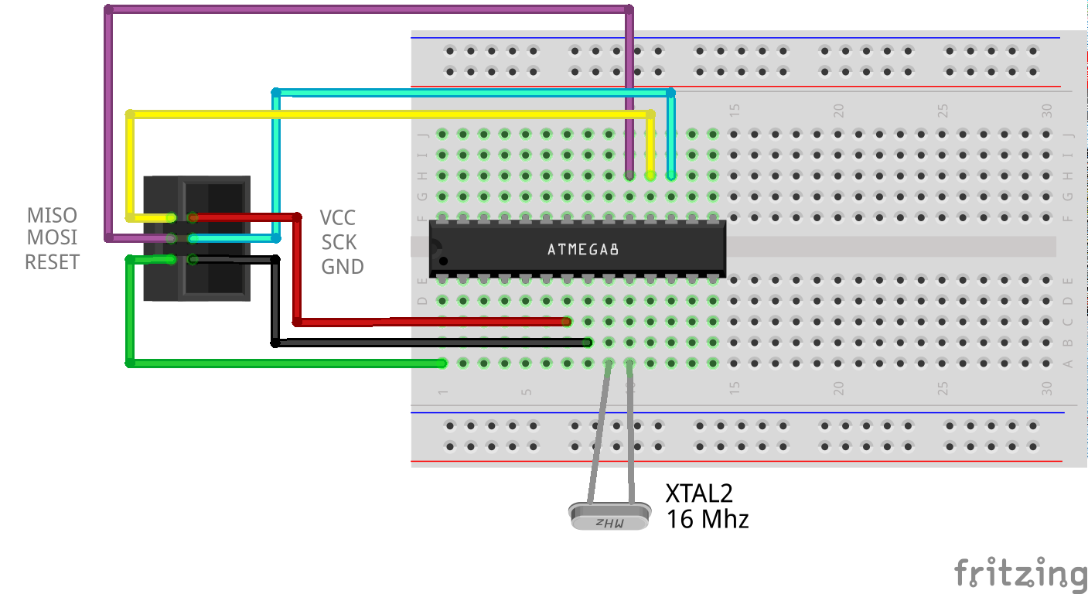
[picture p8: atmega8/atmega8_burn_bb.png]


Basically it's:

| SD reader |Atmega|
|---------------|
|MISO |pin 18: PB4|
|MOSI |pin 17: PB3|
|RESET |pin 01: PC6|
|VCC |pin 20: AVCC|
|SCK |pin 19: PB5|
|GND |pin 22: GND|

Use a 16 Mhz crystal for example, on pin 09 (PB6) and pin 10 (PB7).

Once it's connected, you can program the atmega8 chip with this command-line:

    avrdude -p atmega8 -c USBasp -U flash:w:AY_Emul_244_2ch.hex -U eeprom:w:Conf_standard_24MHz_1_75Mhz.hex -U lfuse:w:0xCE:m -U hfuse:w:0xCF:m 

### Breadboard 

It can also work without the PCB. Just use a breadboard and a few wires!



Please refer to the garvuino/breadboard folder for the fritzing sources and pdf version.

## Expansion board 

The expansion board is a new board for using with the Garvuino or other projects.
Solder 5K or 10K potentiometers onto the board. You don't need to solder the switches, they are not used at the moment.

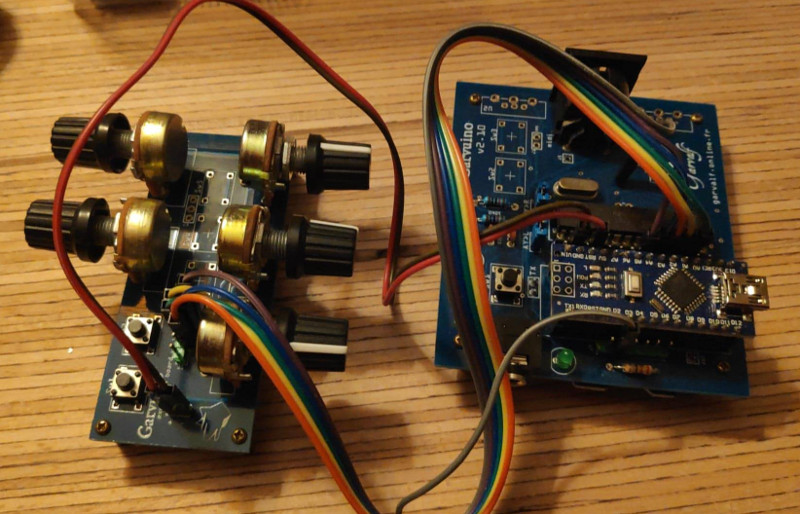
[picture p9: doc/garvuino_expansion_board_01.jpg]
  

Connect the digital pin D3 to the audio out, under the L or R of the AY>L or AY>R pin.

And also connect the 2 right top pins and the 3 bottom pins to the A0 to A4 pins on the arduino, connect the + to 5V and the - to ground, and you'll be able to control the Auduino and Auduino midi sketches found there: https://github.com/farvardin/garvuino/tree/master/arduino_sketches/others

## Links 

 * http://avray.ru/
 * http://playground.arduino.cc/Main/SID-emulator
 * http://randomflux.info/1bit/viewforum.php?id=5
 * https://sensorium.github.io/Mozzi
 * http://risgk.github.io/
 * https://github.com/dzlonline/the_synth
 * https://github.com/ArminJo/Talkie (not included in this repo, but works)

## Credits 

 * Yoruk for his help on the PCB
 * Evgeniy for AVR-AY emulator and invaluable help (initial code by Ramiros)
 * Klaud for help with avr-ay
 * Shiru for the 1-bit engines on Arduino
 * Christoph Haberer and Mario Patino for the Sid-arduino lib
 * The Mozzi team
 * Protodome for the Micro Music Macro Language (μMML) (https://github.com/protodomemusic/mmml) 

## Licence 

This BSD licence is only for the PCB sketch rendition, and code written from scratch. 
Code derived from other projects retains the original licence.
For example Avray is GPLv3.

    BSD 3-Clause License
    Copyright (c) 2015-2017, Garvalf
    All rights reserved.
    
    Redistribution and use in source and binary forms, with or without
    modification, are permitted provided that the following conditions are met:
        * Redistributions of source code must retain the above copyright
          notice, this list of conditions and the following disclaimer.
        * Redistributions in binary form must reproduce the above copyright
          notice, this list of conditions and the following disclaimer in the
          documentation and/or other materials provided with the distribution.
        * Neither the name of the <organization> nor the
          names of its contributors may be used to endorse or promote products
          derived from this software without specific prior written permission.
    
    THIS SOFTWARE IS PROVIDED BY THE COPYRIGHT HOLDERS AND CONTRIBUTORS "AS IS" AND
    ANY EXPRESS OR IMPLIED WARRANTIES, INCLUDING, BUT NOT LIMITED TO, THE IMPLIED
    WARRANTIES OF MERCHANTABILITY AND FITNESS FOR A PARTICULAR PURPOSE ARE
    DISCLAIMED. IN NO EVENT SHALL <COPYRIGHT HOLDER> BE LIABLE FOR ANY
    DIRECT, INDIRECT, INCIDENTAL, SPECIAL, EXEMPLARY, OR CONSEQUENTIAL DAMAGES
    (INCLUDING, BUT NOT LIMITED TO, PROCUREMENT OF SUBSTITUTE GOODS OR SERVICES;
    LOSS OF USE, DATA, OR PROFITS; OR BUSINESS INTERRUPTION) HOWEVER CAUSED AND
    ON ANY THEORY OF LIABILITY, WHETHER IN CONTRACT, STRICT LIABILITY, OR TORT
    (INCLUDING NEGLIGENCE OR OTHERWISE) ARISING IN ANY WAY OUT OF THE USE OF THIS
    SOFTWARE, EVEN IF ADVISED OF THE POSSIBILITY OF SUCH DAMAGE.

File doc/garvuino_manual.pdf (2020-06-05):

# Garvuino Manual

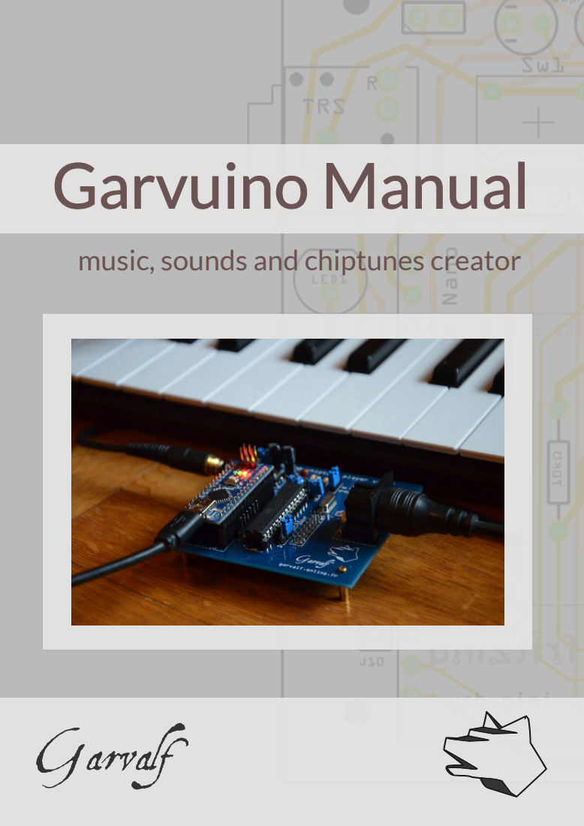
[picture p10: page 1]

music, sounds and chiptunes creator

# GARVUINO

### June 5, 2020

# Contents

1 Presentation of the board | 5
2 Flashing the Garvuino board | 10
3 Assemble the Garvuino board | 16

4 Expansion board | 20
5 Links | 21
6 Credits | 22
7 Licence | 23

Thank you for your interest in Garvuino! The Garvuino is a PCB board for creating music, sounds and chiptunes, either through programming, soundtracker or live recording (midi).
As the hardware is open-source, you can modify, hack and have fun with it without restriction.
The PCB, schematics, code and further instructions can be found on https://github.com/farvardin/garvuino/


# 1 Presentation of the board

Several modes can be used:

## 1.1 AY-3-8910 emulator

On Atmega8 chip, driven by the Arduino nano, from the AVR-AY project

- It can replay Sinclair ZX Spectrum, Atari ST, Amstrad chiptunes from the sd card. You can create thoses chiptunes with Vortex Tracker II or Arkos Tracker.
- It’s possible to use it as a (very simple and dirty) AY soundbox, driven by some external captors (light sensor). But it might not be possible to controle it with MIDI.

## 1.2 Sid emulator

On Arduino, from the sid emulator lib

- It can replay some sid files, from the arduino memory, which is limited (so tunes will be cut). We’d like to find a way to stream the tune from the sd card, it’s probably possible.
- It can be used as a Sid synth, driven by midi.

## 1.3 1-bit music

From various 1-bit engines: http://randomflux.info/1bit/viewforum.php?id=5 (on arduino)

- It can play music from the arduino memory. 1-bit music don’t need much memory so a whole song, even a complex one, can fit in the memory. You can create those songs with Beepola or MilkyTracker.
- It might be possible to stream data from SD if the 1-bit music engine chosen is the same for all the songs.
- It might be possible to create a 1-bit synth in the future. Probably not an easy task.

## 1.4 Mozzi synth

- Mozzy synth, can output fun FM sounds and many other effects.

## 1.5 Hardware

The board has 2 chips :

- an Arduino Nano for the compute (it is a complete board for develop-ment)
- an optional Atmega8 for AY sound output.
A few components :
- a 24 Mhz crystal that is driving the Atmega8
- some capacitors and resistors to filter the output
- a SD card reader to read AY music files (optional)
- a DIN5 midi input to use the board as a midi synth (optional)


The LED is connected to D8 on Arduino. The audio output to D9. The switch to D6. On Garvuino v2.10 and expansion board, the potentiometers are connected to A0 to A1 and to A0 to A4 respectively.
More precisely:
PIN | use
D2 | FREE
D3 | audio out (some sketches)
D4 | CS for SD card reader
D5 | FREE
D6 | switch Sw1 / audio out (some sketches)
D7 | switch Sw3
D8 | led1
D9 | audio out (most sketches)
D10 | switch Sw2
D11 | MOSI: SD card reader
D12 | MISO: SD card reader
D13 | SCK; SD card reader
A0 | POT 1
A1 | POT 2
A2 | POT 3

A3 | POT 4
A4 | SDA: oled display
A5 | SCL: oled display
A6 | POT 5
A7 | FREE

There are a few jumpers on the board. They are for switching between some modes.
When used in AY mode, the mono jumper should be off, when used in beeper, sid or mozzi mode the mono jumper should be on, the J4 (ay chip ground, v1.09 board only) should be off. Also the AY>L and AY>R can be off to reduce noise (but it will work anyway). And TX could be off as well when flashing the arduino chip (you can leave it on, but if the transfer fails, try to remove it)
More detailled informations about the jumpers:
- mono: used in mozzi, 1-bit and sid mode. You can remove the jumper in AY mode because it’s in stereo (but you might also prefer using the mono mode)
- TX: used for transmitting data to the Atmega8 chip in AY mode. You can remove the jumper when not in AY mode. You can also keep it, it doesn’t matter, unless you have some problem for flashing the arduino board. On some boards, the jumper is below the board for easier access to the push button.
- AY>L and AY>R: used in AY mode. You can cut a voice if you remove the jumper. If you remove the jumper when not in AY mode, you’ll be sure there won’t be extra noise from the Atmega8 chip.
- J1: extra midi input GND (below) and midi wire nb 5 if you don’t want to use the DIN5 plug.
- J2/J3: for connecting regular (big) SD reader. Most board will use the smaller SD reader

- J4 / ay chip GND / arduino chip (v1.09 board only): ay chip used in AY mode. It’s better to put the jumper in the "arduino chip" mode (bottom), when not using AY otherwise you’ll get extra and residual noise from the atmega8 chip.
- J5 (v1.09 board only): not used. Linked to midi 4 wire "just in case".
- J6 (v1.09 board only): not used. Could be used to switch off the atmega8 but since there are still some residual noise without it, it can be kept connected. It’s been soldered on most boards.
- J7 (v1.09) / J11 (v2.10): can be used for programming the Arduino for Analog input (potentiomer, light sensor for example)
- J8: not used. Can be connected to arduino +5V, RST, GND and VIN but shouldn’t be necessary.
- J9: can be used for programming the Arduino for digital output (more leds for example)
- J10: not used. Extra digital output.
- Led: for monitoring some infos

You can of course connect audio out to the mini-jack, but it’s also possible to connect a small buzzer (HP), for example 8 ohms / 1 W to the AY>L (under the L) and to the GND (for example in the middle 3-pin J4 or on the GND of J1, if it’s installed) then you’ll get very cheap sound. It can be useful for monitoring.

Midi: You can plug a DIN5 midi cable into the dedicated port. When removing it, please do it slowly, to avoid tearing everything apart. And when pluging it in and out, hold the midi port with your hand to avoid extra pressure on the connexions.

You can also use hairless midi serial bridge (windows, mac os x, linux) or ttymidi (linux) to create a virtual connection going through serial port. You’ll need to adjust the arduino sketch to enable this (search for hairless midi or ttymidi in the sketch, or for #define USBMIDI at the begining of the sketch).

# 2 Flashing the Garvuino board

This board is supposed to work extensively with the Arduino IDE (http://arduino.cc/). You must download it and use it for developping, changing sounds and engines. The only exception is if you only intend to use the board as a AY player, then you can just change the tunes on the SD card.
Programs on Arduino are called sketches. Most sketches are tested with Arduino IDE 1.8.# but they should work with IDE 1.6.#. With latest arduino IDE (1.8.9), you must select: Processor: "Atmega328 (old bootloader)".
Get the sketches from there: https://github.com/farvardin/garvuino/archive/master.zip
For flashing, just launch the Arduino IDE, connect the arduino to your computer using an USB mini cable, select in the tools>arduino nano, atmega328(P)(old bootloader, if applicable), select the right port.
Load a sketch from the arduino_sketches/ folder.
For flashing, you need to unplug the midi cable from your synth ir garvuino if it’s connected, or powerdown the synth. If you want to develop a sketch on garvuino, it can be tiresome to always unplug the midi. You can use a simpler wire <=> midi connected to the J1, with GND to midi GND (pin 2) and the other slot (which is connected to the RXD port) to the midi pin 5, this way it’s faster to unplug. Or use ttymidi or hairless midi serial to usb port (see above)
In the case you get a:

avrdude: stk500_getsync() attempt 1 of 10: not in sync: resp=0x32
it can be from different causes. If the midi plug is connected, see advice above. But it can also appear at random occasions. I suspect it’s because of some electricity in the atmega8 chip. In this case, you can remove the TX jumper (above the arduino nano). You only need it connected when playing AY chiptunes (see below). This kind of message can also be seen if you’ve choosen the wrong port to connect the arduino.

## 2.1 Flashing for AY music

Just load avray/avray_sd_sketch/avray_sd_sketch.ino, put some tunes from tunes/aym_tunes/1_75MHz/rsf/ into your SD card and power the device! If you create your own tunes (using Vortex Tracker II for example), you’ll need to convert them to RSF using the AVR-AY player: http://www.avray.ru/avr-ay-player/
You can also create tunes using Deflemask (choose Master System SN76489 PSG) or Bamboo Tracker (use only the SSC channels) and convert the exported VGM tunes to RSF using the vgm2rsf tool: https://github.com/farvardin/garvuino/tree/master/tools/vgm2rsf

## 2.2 Sid emulator

load /sid/sid_midi/sid_midi.ino for the Sid emulator synth. Change sound mode with the switch. You can change some sound with knobs on your keyboard. The sketch is programmed for my Behringer UMA25S keyboard, knob E09 to E13 (midi control 71 to 75).
There is also a sid player (/sid/sid_player/) which can load some SID data and play it from the arduino (at the moment it can only load from memory, which isn’t big enough for a complete song).
You can also connect a gyroscope module to the Garvuino and have fun with sounds. See sid/gyro_header_sid/ for this.

## 2.3 Flashing for 1-bit music

Only one 1-bit music can be installed into the Arduino at a time. Load a sketch, for example beeper/arduino_qchan/arduino_qchan.ino and flash the Arduino. Music should go out of the mini-jack now!

You can compose music using the beepola tracker.
Beepola can use the Tritone, Qchan and Phaser1 engines.
There are python converters in the folder to convert your own music to arduino code. Just make it into beepola and "compile" it to .bin format in the tools menu (without song engine, "song data only"). Convert the bin to data readable by the arduino with the python script.
Then include your code into the arduino sketch (use #include "your_song.h" instead of #include "music_data.h" for example.) Use the line that is not commented (a comment on arduino starts with with two /) For the octode engine, you’ll have to edit a .xm file with a tracker like milkytracker. See http://battleofthebits.org/lyceum/View/Octode for more informations. There is a xm to arduino converter in the arduino_octode folder as well.
Read more on the 1-bit forum thread (search for arduino)
If you have some problem for creating your own music and exporting it to arduino, you can join the 1-bit forum to request for help.

## 2.4 Flashing for Mozzi synth

There are several examples in the mozzi/ folder, just try them out!
You can also use most mozzi examples from the original library (see Examples/Mozzi in the Arduino IDE).

## 2.5 Flashing other sketches

The Garvuino should be able to play many other sketches from various projects on internet.

2.5.1

Playtune

This one can play some MIDI files after converting them:

https://bitbucket.org/farvardin/playtune-arduino
Just connect PIN 5 to AY>L and PIN 6 to AY>R (PIN 9 is already connected to audio output) and you’ll get a midi player able to play up to 3 voices. You can connect even more voices to the free Digital Output on the Garvuino (for example by adding a pin on PIN 10.
Use the examples/test_nano/test_nano.in sketch.

2.5.2

Auduino

The Auduino is a project for using granular synthesis with 5 potentiometers, you’ll have to connect PIN3 from the arduino to the AY>L audio output (read the sketch header for more informations).

2.5.3

"The Synth"

"The Synth" is a project for using Arduino as a monophonic wavetables synth. It’s lightweight and easy to hack.
You’ll have to connect PIN3 from the arduino to the AY>L audio output (read the sketch header for more informations). https://www.instructables.com/id/Turn-your-Arduino-into-a-4-voice-wavetable-synth-w/

2.5.4

Digital Synth VRA8

VRA8 is an awesome project with several different monophonic and polyphonic synths for Arduino.
It’s compatible with the Garvuino. Get more informations for how to use it on http://risgk.github.io/.

You’ll have to connect PIN6 from the arduino to the AY>L audio output. https://www.instructables.com/id/Digital-Synth-VRA8-Px-for-Arduino-Uno/
For hairless midi, get it on https://projectgus.github.io/hairless-midiserial/ On Debian based systems, to run it, you’ll probably need to install libsm6, libxrender, libasound2 and libasound2-plugins (for i386):

sudo apt install libsm6:i386 libxrender1:i386 libasound2:i386 libasound2-plugins:i386
Run the arduino sketch (using the 1.8.5 or below IDE for example). Close Arduino IDE.
Start Hairless MIDI. In prefs, change Baud rate to 38400. Select "Serial Port": USB-serial adapter.
Start virtual midi port with:

sudo modprobe snd-virmidi
In hairless midi window, select a virtual Raw midi port in Midi Out. Then, in Midi In, "serial->Midi" should appear.
Visit http://risgk.github.io/digital-synth-vra8-px/vra8-px-ctrl.html with Chrome (or Chromium). Select RtMidi input in the web page (in the MIDI OUT list).
Now you should get some sounds from this wonderful synth.
In the case you need to reflash the Arduino, just uncheck the "serial<->midi bridge on" button in Hairless midi, and check it again to transmit midi.

2.5.5

MMML

Micro Music Macro Language (MML) (https://github.com/protodomemusic/mmml) is using AVR programming to flash Atmega chips (Attiny85, Atmega168...).
It works too with the Atmega8 found on the Garvuino!

To make it work, you’ll have to reflash the firmware of the atmega8 (or get another chip) using an USBasp. You can learn more about this in the "Atmega8 setup and flashing" section of this manual.
And to use the arduino as a power supply, just remove the arduino chip from its socket, connect the 5V from the arduino to the PIN 7 on the atmega8, connect arduino GND to atmega8 PIN 8, connect a passive speaker to atmega8 PIN 22 (another GND) and to atmega8 PIN 14 (PB0)

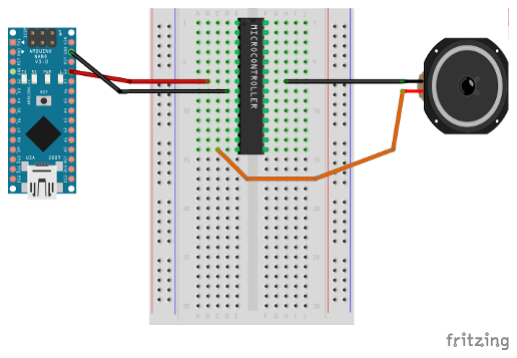
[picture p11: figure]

You can also use the Garvuino as an audio output, instead of the speaker, just connect PIN 14 to the empty arduino socket, in the D9 hole (4th from the bottom left), and PIN 22 to the GND hole (2nd from the top right)

# 3 Assemble the Garvuino board

If you got the board through a kit, soldering it should be pretty simple as there are only basic components.
If you have no clue about soldering, this guide might be of some use for you: https://www.makerspaces.com/how-to-solder/
Solder the resistors and capacitors first for example, then the jumpers, socket, led, switch, crystal and audio jack. In any case, the regular sd card reader should be soldered after all of this.
If you use a micro-sd reader, it could be better to solder first the left socket for the atmega8 chip (by side of the arduino chip), then the other elements (led, resistor, pins), then the micro-sd reader, then the right part of the socket for the atmega8 chip, otherwise it’s more difficult to solder the micro-sd reader, yet still possible.
There is a little error on the version 1.09 / 2017-08 of the PCB board, which I’ve fixed with a wire. On this version, the D6 output on arduino is shared with the LED so it might not always be available on some sketches.

## 3.1 Bill of Materials

Name | nb | (optional part)
Garvuino PCB | 1
crystal 24 mhz | 1
arduino nano | 1
atmega8 | 1
ceramic capacitor 820 pF | 2
electrolytic capac. 10 uF | 2
ceramic capacitor 100 nF | 1 | x

led | 1 | x
DIN5 connector (midi) | 1 | x
1 k Resistor | 1 | x
10 k Resistor | 2
micro sd module | 1
momentary switch (6x6mm type) | 1
audio jack 3.5 mm (TRS) | 1
jumper | 6
female header socket PCB 2.54mm 1
male pin strips 2.54 | 1
female pin strips 2.54 | 1

## 3.2 Atmega8 setup and flashing

If you’ve bought the Garvuino assembled or in a kit, the atmega8 is already flashed for AY emulation. Yet, you might want to install a new revision of the AVRAY program, and use different speed and settings. Here are the instructions:
Get a "USBASP USB ISP Programmer & 10 Pin ISP interface Cable - AVR ATMEL ATMega".
Connect it according to this schematic for the atmega8:

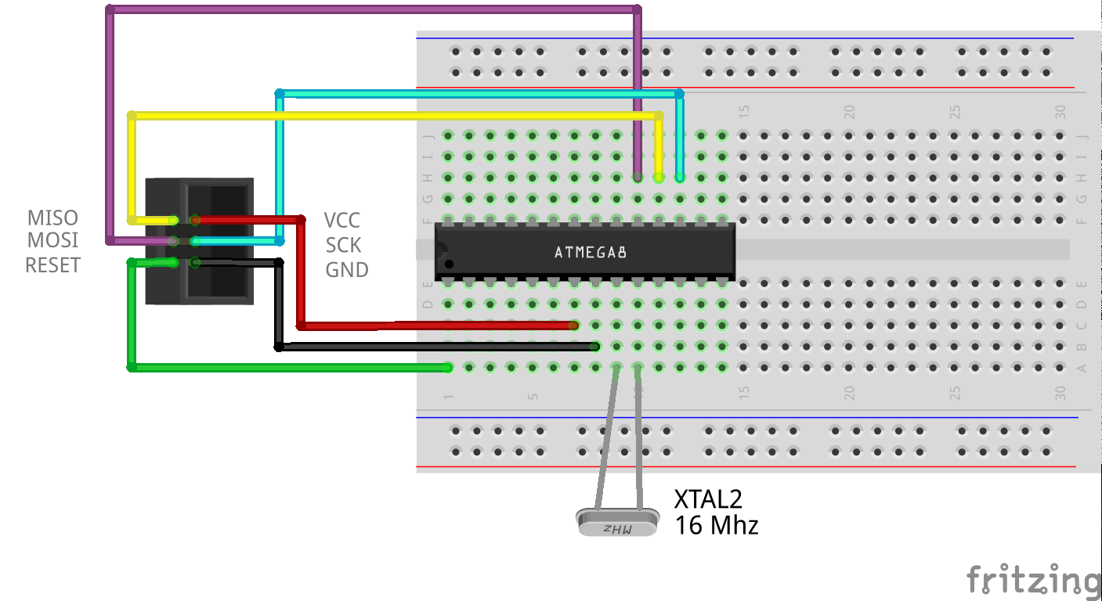
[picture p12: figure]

Basically it’s:

SD reader | Atmega
MISO | pin 18: PB4
MOSI | pin 17: PB3
RESET | pin 01: PC6
VCC | pin 20: AVCC
SCK | pin 19: PB5
GND | pin 22: GND

Use a 16 Mhz crystal for example, on pin 09 (PB6) and pin 10 (PB7). Once it’s connected, you can program the atmega8 chip with this command-line:

avrdude -p atmega8 -c USBasp -U flash:w:AY_Emul_244_2ch.hex -U eeprom:w:Conf_standard_24MHz_1_75Mhz.hex -U lfuse:w:0xCE:m -U hfuse:w:0xCF:m

## 3.3 Breadboard

It can also work without the PCB. Just use a breadboard and a few wires!


Please refer to the garvuino/breadboard folder for the fritzing sources and pdf version.

# 4 Expansion board

The expansion board is a new board for using with the Garvuino or other projects. Solder 5K or 10K potentiometers onto the board. You don’t need to solder the switches, they are not used at the moment.


Connect the digital pin D3 to the audio out, under the L or R of the AY>L or AY>R pin.
And also connect the 2 right top pins and the 3 bottom pins to the A0 to A4 pins on the arduino, connect the + to 5V and the - to ground, and you’ll be able to control the Auduino and Auduino midi sketches found there: https://github.com/farvardin/garvuino/tree/master/arduino_sketches/others

# 5 Links

- http://avray.ru/
- http://playground.arduino.cc/Main/SID-emulator
- http://randomflux.info/1bit/viewforum.php?id=5
- https://sensorium.github.io/Mozzi
- http://risgk.github.io/
- https://github.com/dzlonline/the_synth
- https://github.com/ArminJo/Talkie (not included in this repo, but works)

# 6 Credits

- Yoruk for his help on the PCB
- Evgeniy for AVR-AY emulator and invaluable help (initial code by Ramiros)
- Klaud for help with avr-ay
- Shiru for the 1-bit engines on Arduino
- Christoph Haberer and Mario Patino for the Sid-arduino lib
- The Mozzi team
- Protodome for the Micro Music Macro Language (MML) (https://github.com/protodomemusic/mmml)

# 7 Licence

This BSD licence is only for the PCB sketch rendition, and code written from scratch. Code derived from other projects retains the original licence. For example Avray is GPLv3.

BSD 3-Clause License
Copyright (c) 2015-2017, Garvalf
All rights reserved.

Redistribution and use in source and binary forms, with or without modification, are permitted provided that the following conditions are met:
* Redistributions of source code must retain the above copyright notice, this list of conditions and the following disclaimer. * Redistributions in binary form must reproduce the above copyright
notice, this list of conditions and the following disclaimer in the
documentation and/or other materials provided with the distribution.
* Neither the name of the <organization> nor the
names of its contributors may be used to endorse or promote products
derived from this software without specific prior written permission.

THIS SOFTWARE IS PROVIDED BY THE COPYRIGHT HOLDERS AND CONTRIBUTORS "AS IS" AND
ANY EXPRESS OR IMPLIED WARRANTIES, INCLUDING, BUT NOT LIMITED TO, THE IMPLIED

WARRANTIES OF MERCHANTABILITY AND FITNESS FOR A PARTICULAR PURPOSE ARE
DISCLAIMED. IN NO EVENT SHALL <COPYRIGHT HOLDER> BE LIABLE FOR ANY DIRECT, INDIRECT, INCIDENTAL, SPECIAL, EXEMPLARY, OR CONSEQUENTIAL DAMAGES
(INCLUDING, BUT NOT LIMITED TO, PROCUREMENT OF SUBSTITUTE GOODS OR SERVICES;
LOSS OF USE, DATA, OR PROFITS; OR BUSINESS INTERRUPTION) HOWEVER CAUSED AND
ON ANY THEORY OF LIABILITY, WHETHER IN CONTRACT, STRICT LIABILITY, OR TORT
(INCLUDING NEGLIGENCE OR OTHERWISE) ARISING IN ANY WAY OUT OF THE USE OF THIS
SOFTWARE, EVEN IF ADVISED OF THE POSSIBILITY OF SUCH DAMAGE.

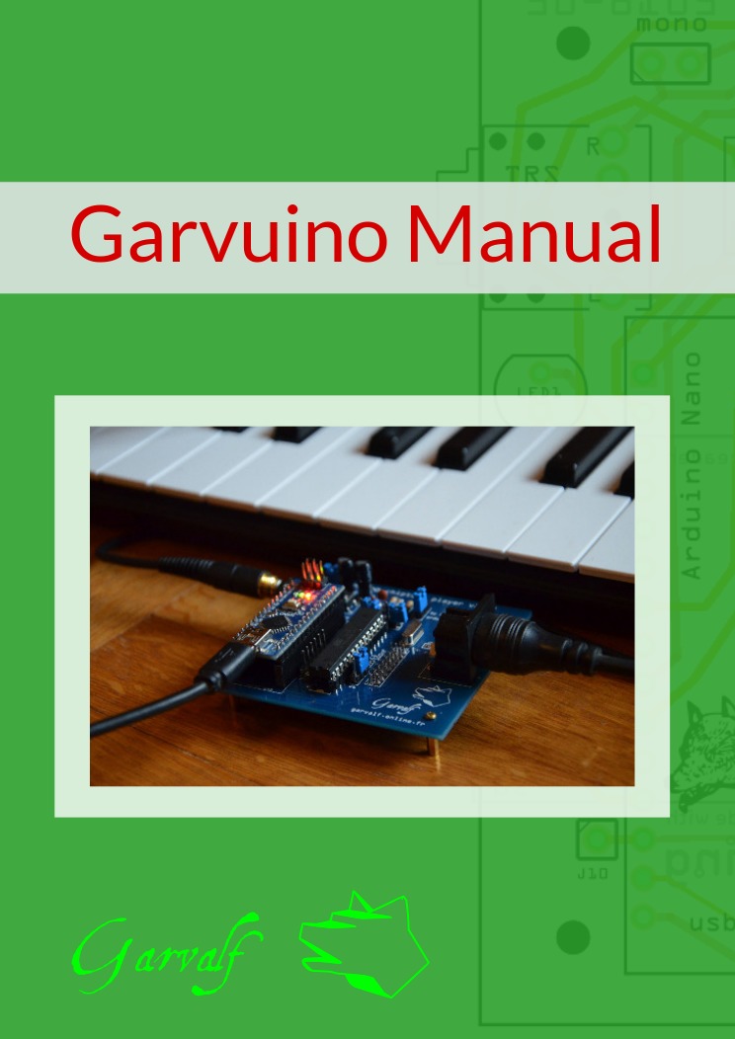
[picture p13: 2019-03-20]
doc/garvuino_manual.jpg

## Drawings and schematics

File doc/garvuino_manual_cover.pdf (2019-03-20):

# Garvuino Manual

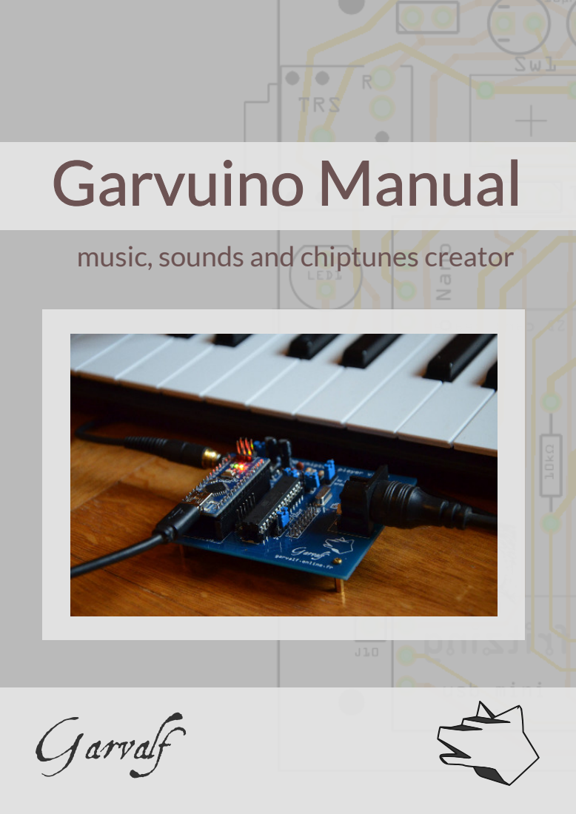
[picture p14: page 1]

music, sounds and chiptunes creator

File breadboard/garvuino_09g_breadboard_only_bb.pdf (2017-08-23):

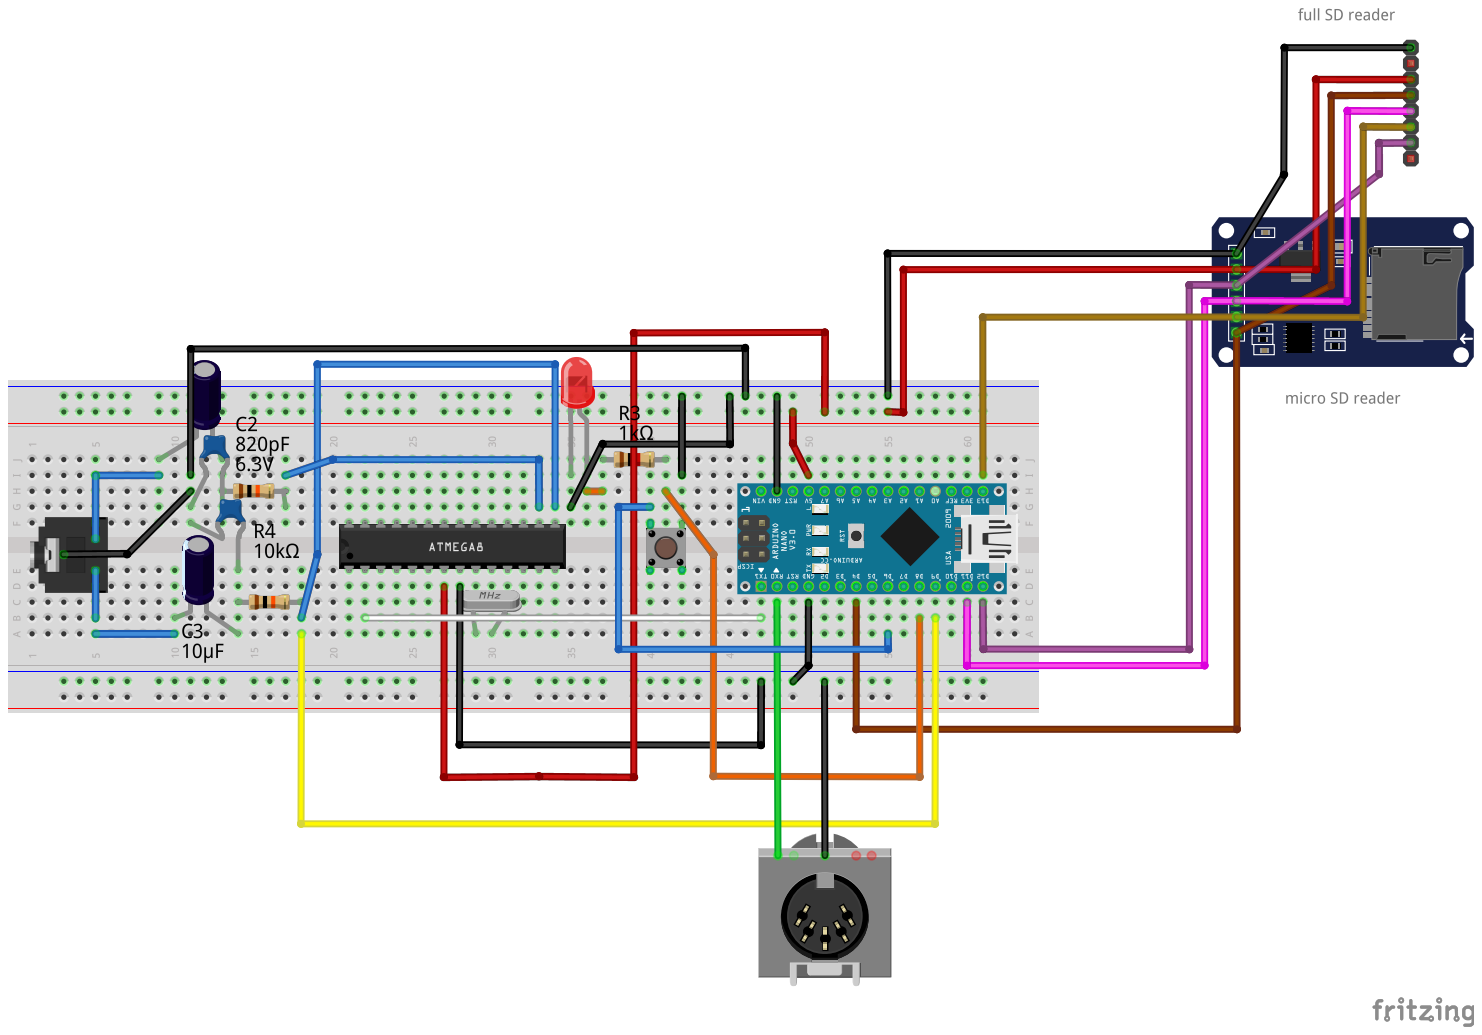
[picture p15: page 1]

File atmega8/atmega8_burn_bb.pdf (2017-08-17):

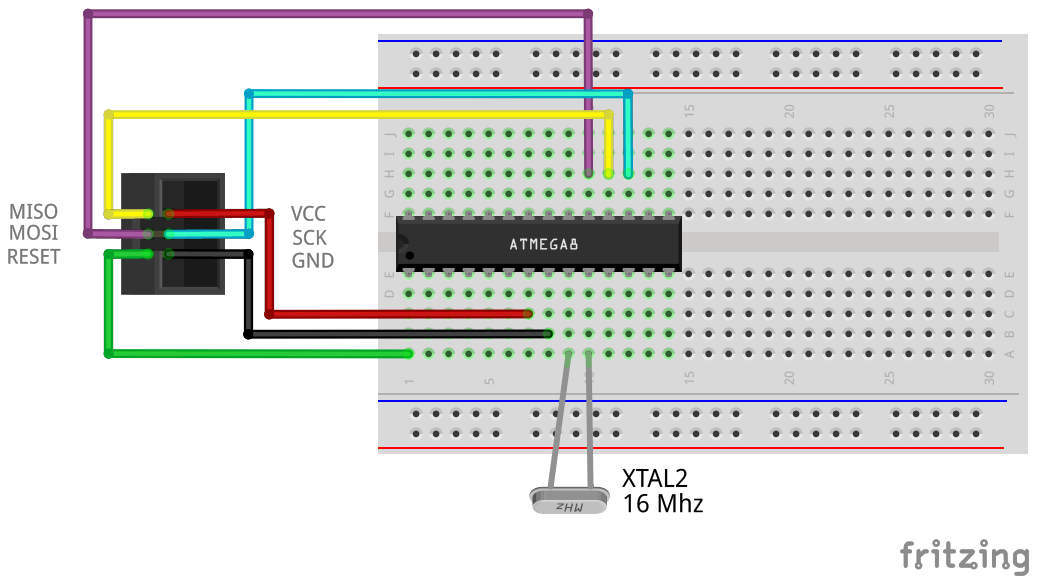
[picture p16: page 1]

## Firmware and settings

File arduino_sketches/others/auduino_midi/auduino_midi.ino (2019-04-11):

// ************************************************************************
// AUDUINO - MIDI Upgrade v1.1
// Auduino, the Lo-Fi granular synthesiser
//
// MIDI programming by David Benn http://www.notesandvolts.com
//
// Tutorial - http://www.notesandvolts.com/2015/05/auduino-synth-midi.html
// 
// ** Requires Arduino MIDI Library v4.2 or later **
//
// Based on the Auduino Synthesizer v5 by Peter Knight http://tinker.it
// ************************************************************************
// Version 1.0 - Initial release
// Version 1.1 - Fixed bug that caused note to hang with some DAWs
// ************************************************************************
// Analog in 0: Grain 1 pitch
// Analog in 1: Grain 2 decay
// Analog in 2: Grain 1 decay
// Analog in 3: Grain 2 pitch
// Analog in 6: Grain repetition frequency
//
// Digital 3: Audio out 
// Change the line beginning with syncPhaseInc in the main loop to choose between chromatic and pentatonic
//
// On GARVUINO v2.10: connect PIN3 to PIN AY>L or AY>R (under the L or R) to make the audio output!
// On GARVUINO v1.09: remove the arduino out of the socket
//      and connect directly the analog input A0, A1, A2, A3 and A6, and the 5V to the extension board. 
//      Then connect PIN3 to PIN AY>L (under the L label) and GND to the GND in J1 on Garvuino
//      in order to get the audio output!
//   
//       A0A1A2
//     +---------+
//     | x x x   |
//     | x x x x |
//     +---------+
//       A3A6     (the two other pin on the right are for connecting switches)
//
//
// If you have one, connect the OLED on A4 and A5. Use ssd1306: https://github.com/lexus2k/ssd1306


#include <avr/io.h>
#include <avr/interrupt.h>
#include <MIDI.h> // Requires Arduino MIDI Library v4.2 or later

// *** MIDI Parameters ***********************************************************
#define BENDRANGE 12 // Change to set Number of Semitones for Pitch Bend (1 to 24)
// *******************************************************************************
// If the DIP Switch option is installed - leave dipSwitchInstalled as true
const bool dipSwitchInstalled = false;
// DIP Switch Setting = Channel (1=ON, 0=OFF)
// 0000 = 1   0001 = 2   0010 = 3   0011 = 4
// 0100 = 5   0101 = 6   0110 = 7   0111 = 8
// 1000 = 9   1001 = 10  1010 = 11  1011 = 12
// 1100 = 13  1101 = 14  1110 = 15  1111 = 16
//
// If DIP Switch is NOT installed - change dipSwitchInstalled to "false"
// If dipSwitchInstalled is set to false, the MIDI channel will be set
// to the value of MIDICHANNEL
#define MIDICHANNEL 1 // Can be a value from 1 to 16
// *******************************************************************************

MIDI_CREATE_DEFAULT_INSTANCE();

uint16_t syncPhaseAcc;
uint16_t syncPhaseInc;
uint16_t grainPhaseAcc;
uint16_t grainPhaseInc;
uint16_t grainAmp;
uint8_t grainDecay;
uint16_t grain2PhaseAcc;
uint16_t grain2PhaseInc;
uint16_t grain2Amp;
uint8_t grain2Decay;

// push button
int switchInPin = 6;
int buttonRead = HIGH; 
byte mode=0;

//int LedPin = 8;
#define LED 8    


// DIP Switch Pins
#define DIP_SW1 6
#define DIP_SW2 7
#define DIP_SW3 8
#define DIP_SW4 5

// Map Analogue channels
#define SYNC_CONTROL         (6)  // 4 in original sketch, without OLED
#define GRAIN_FREQ_CONTROL   (0)
#define GRAIN_DECAY_CONTROL  (2)
#define GRAIN2_FREQ_CONTROL  (3)
#define GRAIN2_DECAY_CONTROL (1)

#define BUFFER 8 //Size of keyboard buffer

#if defined(__AVR_ATmega8__)
//
// On old ATmega8 boards.
//    Output is on pin 11
//
#define LED_PIN       13
#define LED_PORT      PORTB
#define LED_BIT       5
#define PWM_PIN       11
#define PWM_VALUE     OCR2
#define PWM_INTERRUPT TIMER2_OVF_vect
#elif defined(__AVR_ATmega1280__)
//
// On the Arduino Mega
//    Output is on pin 3
//
#define LED_PIN       13
#define LED_PORT      PORTB
#define LED_BIT       7
#define PWM_PIN       3
#define PWM_VALUE     OCR3C
#define PWM_INTERRUPT TIMER3_OVF_vect
#else
//
// For modern ATmega168 and ATmega328 boards
//    Output is on pin 3
//
#define PWM_PIN       3
#define PWM_VALUE     OCR2B
#define LED_PIN       13
#define LED_PORT      PORTB
#define LED_BIT       5
#define PWM_INTERRUPT TIMER2_OVF_vect
#endif

// Smooth logarithmic mapping
//
uint16_t antilogTable[] = {
  64830, 64132, 63441, 62757, 62081, 61413, 60751, 60097, 59449, 58809, 58176, 57549, 56929, 56316, 55709, 55109,
  54515, 53928, 53347, 52773, 52204, 51642, 51085, 50535, 49991, 49452, 48920, 48393, 47871, 47356, 46846, 46341,
  45842, 45348, 44859, 44376, 43898, 43425, 42958, 42495, 42037, 41584, 41136, 40693, 40255, 39821, 39392, 38968,
  38548, 38133, 37722, 37316, 36914, 36516, 36123, 35734, 35349, 34968, 34591, 34219, 33850, 33486, 33125, 32768
};
uint16_t mapPhaseInc(uint16_t input) {
  return (antilogTable[input & 0x3f]) >> (input >> 6);
}

// Stepped chromatic mapping
//
uint16_t midiTable[] = {
  0, 18, 19, 20, 22, 23, 24, 26, 27, 29, 31, 32, 34, 36, 38, 41, 43, 46, 48, 51, 54, 58, 61, 65, 69, 73,
  77, 82, 86, 92, 97, 103, 109, 115, 122, 129, 137, 145, 154, 163, 173, 183, 194, 206, 218, 231,
  244, 259, 274, 291, 308, 326, 346, 366, 388, 411, 435, 461, 489, 518, 549, 581, 616, 652, 691,
  732, 776, 822, 871, 923, 978, 1036, 1097, 1163, 1232, 1305, 1383, 1465, 1552, 1644, 1742,
  1845, 1955, 2071, 2195, 2325, 2463, 2610, 2765, 2930, 3104, 3288, 3484, 3691, 3910, 4143,
  4389, 4650, 4927, 5220, 5530, 5859, 6207, 6577, 6968, 7382, 7821, 8286, 8779, 9301, 9854,
  10440, 11060, 11718, 12415, 13153, 13935, 14764, 15642, 16572, 17557, 18601, 19708, 20879,
  22121, 23436, 24830, 26306
};
uint16_t mapMidi(uint16_t input) {
  return (midiTable[input]);
}

// Stepped Pentatonic mapping
//
uint16_t pentatonicTable[54] = {
  0, 19, 22, 26, 29, 32, 38, 43, 51, 58, 65, 77, 86, 103, 115, 129, 154, 173, 206, 231, 259, 308, 346,
  411, 461, 518, 616, 691, 822, 923, 1036, 1232, 1383, 1644, 1845, 2071, 2463, 2765, 3288,
  3691, 4143, 4927, 5530, 6577, 7382, 8286, 9854, 11060, 13153, 14764, 16572, 19708, 22121, 26306
};

uint16_t mapPentatonic(uint16_t input) {
  uint8_t value = (1023 - input) / (1024 / 53);
  return (pentatonicTable[value]);
}

//Global Varibles used by MIDI Upgrade
byte note = 0;
byte buff[BUFFER];
byte buffersize = 0;
float bendfactor = ((BENDRANGE * 100.0) / 8190.0);
float cents = 0;
bool pot = false;
bool noteOn = false;
int oldpot = 0;
int transpose = 0;

void audioOn() {
#if defined(__AVR_ATmega8__)
  // ATmega8 has different registers
  TCCR2 = _BV(WGM20) | _BV(COM21) | _BV(CS20);
  TIMSK = _BV(TOIE2);
#elif defined(__AVR_ATmega1280__)
  TCCR3A = _BV(COM3C1) | _BV(WGM30);
  TCCR3B = _BV(CS30);
  TIMSK3 = _BV(TOIE3);
#else
  // Set up PWM to 31.25kHz, phase accurate
  TCCR2A = _BV(COM2B1) | _BV(WGM20);
  TCCR2B = _BV(CS20);
  TIMSK2 = _BV(TOIE2);
#endif
}

#include "ssd1306.h"  // oled display by Alexey Dynda

#include "garvuino.h"  // 


void setup() {
  if (dipSwitchInstalled) {
    pinMode(DIP_SW1, INPUT_PULLUP);
    pinMode(DIP_SW2, INPUT_PULLUP);
    pinMode(DIP_SW3, INPUT_PULLUP);
    pinMode(DIP_SW4, INPUT_PULLUP);
  }
  pinMode(PWM_PIN, OUTPUT);
  audioOn();
  pinMode(LED_PIN, OUTPUT);
  oldpot = analogRead(SYNC_CONTROL);
  if (dipSwitchInstalled) {
    MIDI.begin(DipSwitch());
  }
  else {
    MIDI.begin(MIDICHANNEL);
  }
  MIDI.setHandleNoteOn(NoteOnMidi);
  MIDI.setHandleNoteOff(NoteOffMidi);
  MIDI.setHandlePitchBend(Pitchbend);

  ssd1306_128x64_i2c_init();

  ssd1306_fillScreen(0x00);
    ssd1306_drawBitmap(0, 0, 128, 64, garvuino_logo);
    delay(20);
    welcome();
    
}

static void welcome()
{
    ssd1306_setFixedFont(ssd1306xled_font6x8);
    //ssd1306_clearScreen();
    ssd1306_printFixed(0,  62, "Garvuino", STYLE_NORMAL);
    ssd1306_printFixed2x(0,  2, "    ", STYLE_NORMAL);
    delay(50);
    
}

void loop() { // *** MAIN LOOP ***

  MIDI.read();


  if (abs(analogRead(SYNC_CONTROL) - oldpot) > 5) pot = true;// Check if SYNC Pot has been touched

  // If Sync pot has been touched - Play pentatonic major scale with Root Note set by note on keyboard
  if (pot == true && noteOn == true) {
    // we disable this to avoid random notes / glitches. Uncomment to enable again pitch pot:
   // syncPhaseInc = (mapPentatonic(analogRead(SYNC_CONTROL)) * pow(2, ((cents + transpose) / 1200)) );
    oldpot = analogRead(SYNC_CONTROL);
  }
  // If Sync pot has not been touched - Play the note sent by keyboard
  else {
 
   syncPhaseInc = mapMidi(note) * pow(2, (cents / 1200));
  }

  grainPhaseInc  = mapPhaseInc(analogRead(GRAIN_FREQ_CONTROL)) / 2;
  grainDecay     = analogRead(GRAIN_DECAY_CONTROL) / 8;
  grain2PhaseInc = mapPhaseInc(analogRead(GRAIN2_FREQ_CONTROL)) / 2;
  grain2Decay    = analogRead(GRAIN2_DECAY_CONTROL) / 4;
}

SIGNAL(PWM_INTERRUPT)
{
  uint8_t value;
  uint16_t output;

  syncPhaseAcc += syncPhaseInc;
  if (syncPhaseAcc < syncPhaseInc) {
    // Time to start the next grain
    grainPhaseAcc = 0;
    grainAmp = 0x7fff;
    grain2PhaseAcc = 0;
    grain2Amp = 0x7fff;
    LED_PORT ^= 1 << LED_BIT; // Faster than using digitalWrite
  }

  // Increment the phase of the grain oscillators
  grainPhaseAcc += grainPhaseInc;
  grain2PhaseAcc += grain2PhaseInc;

  // Convert phase into a triangle wave
  value = (grainPhaseAcc >> 7) & 0xff;
  if (grainPhaseAcc & 0x8000) value = ~value;
  // Multiply by current grain amplitude to get sample
  output = value * (grainAmp >> 8);

  // Repeat for second grain
  value = (grain2PhaseAcc >> 7) & 0xff;
  if (grain2PhaseAcc & 0x8000) value = ~value;
  output += value * (grain2Amp >> 8);

  // Make the grain amplitudes decay by a factor every sample (exponential decay)
  grainAmp -= (grainAmp >> 8) * grainDecay;
  grain2Amp -= (grain2Amp >> 8) * grain2Decay;

  // Scale output to the available range, clipping if necessary
  output >>= 9;
  if (output > 255) output = 255;

  // Output to PWM (this is faster than using analogWrite)
  PWM_VALUE = output;
}

// NoteOnMidi function is called when a Note On event is detected
// Put note in key buffer and set note variable
void NoteOnMidi(byte channel, byte pitch, byte velocity) {
  if (buffersize < BUFFER) {
    note = pitch;
    buff[buffersize] = pitch;
    buffersize++;
  }
  noteOn = true;
  // Set root note of Pentatonic scale
  int offset = pitch % 12;
  if (offset < 7) transpose = (5 + offset) * 100;
  else if (offset >= 7) transpose = (offset - 7) * 100;
}

void changeMode()
{
    mode++; 
    Serial.println("Mode: ");  Serial.println(mode);
      if (mode==0) { garvuino_BlinkLed(1); garvuino_redrawLogo(); ssd1306_printFixed2x(0,  2, "mode 1", STYLE_NORMAL);}
      if (mode==1) { garvuino_BlinkLed(2); garvuino_redrawLogo(); ssd1306_printFixed2x(0,  2, "mode 2", STYLE_NORMAL);}
      if (mode==2) { garvuino_BlinkLed(3); garvuino_redrawLogo(); ssd1306_printFixed2x(0,  2, "mode 3", STYLE_NORMAL);}
      if (mode==3) { garvuino_BlinkLed(4); garvuino_redrawLogo();}
        if (mode==4) {
                 mode=-1;              
               }
}

// NoteOffMidi function is called when a Note Off event is detected
// If there are other notes in the key buffer (more than one key held)
// re-trigger old note. If key buffer is empty - set note to zero (off).
void NoteOffMidi(byte channel, byte pitch, byte velocity) {
  if (buffersize > 1) {
    for (int ctr = 0; ctr < buffersize; ctr++) {
      if (buff[ctr] == pitch) {

        ShiftLeft(ctr + 1);
        break;
      }
    }
    note = buff[buffersize - 1];
    int offset = note % 12;
    if (offset < 7) transpose = (5 + offset) * 100;
    else if (offset >= 7) transpose = (offset - 7) * 100;
  }
  else {
    note = 0;
    noteOn = false;
    buff[buffersize - 1] = 0;
    buffersize = 0;
  }
  pot = false;
}

// ShiftLeft closes gap in key buffer when note is removed.
void ShiftLeft(int index) {
  int ctr = (index - 1);
  for (ctr; ctr < buffersize - 1; ctr++) {
    buff[ctr] = buff[ctr + 1];
  }
  buff[ctr + 1] = 0;
  buffersize--;
}

// Pitchbend function is called when Pitchbend data is received.
// This function coverts the Pitchbend number into cents (100 cents = 1 semitone)
// In the main loop, the frequency of the note plus the pitchbend is calculated
// using this formula: Final Frequency = note * 2^(cents/1200)
void Pitchbend (byte channel, int bend) {
  cents = bend * bendfactor;
}

byte DipSwitch() {
  byte value = 0;
  if (digitalRead(DIP_SW4) == LOW)
    value += 1;
  if (digitalRead(DIP_SW3) == LOW)
    value += 2;
  if (digitalRead(DIP_SW2) == LOW)
    value += 4;
  if (digitalRead(DIP_SW1) == LOW)
    value += 8;
  return (value + 1);
}

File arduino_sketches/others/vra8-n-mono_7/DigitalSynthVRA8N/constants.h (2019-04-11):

#pragma once

const double    A4_PITCH = 440.0;

const uint8_t   MIDI_CH             = 0;
const uint16_t  SAMPLING_RATE       = 31250;
const uint16_t  FREQUENCY_MAX       = 15624;
const uint8_t   BIT_DEPTH           = 8;
const uint8_t   NOTE_NUMBER_MIN     = 0;
const uint8_t   NOTE_NUMBER_MAX     = 120;
const uint8_t   NOTE_NUMBER_INVALID = 255;

const uint8_t   PROGRAM_NUMBER_MAX  = 7;

const uint8_t   OSC_CONTROL_INTERVAL_BITS    = 2;
const uint8_t   OSC_CONTROL_INTERVAL         = 0x01 << OSC_CONTROL_INTERVAL_BITS;
const uint8_t   OSC_PHASE_RESOLUTION_BITS    = 24;
const uint8_t   OSC_TUNE_TABLE_STEPS_BITS    = 8;
const uint8_t   OSC_TUNE_DENOMINATOR_BITS    = 9;
const uint8_t   OSC_WAVE_TABLE_AMPLITUDE     = 96;
const uint8_t   OSC_WAVE_TABLE_SAMPLES_BITS  = 8;
const uint8_t   OSC_DETUNE_MUL_NUM_BITS      = 4;
const uint16_t  OSC_DETUNE_FREQ_MIN          = 64;
const uint16_t  OSC_DETUNE_FREQ_MAX          = 0;
const uint8_t   FILTER_CONTROL_INTERVAL_BITS = 3;
const uint8_t   FILTER_CONTROL_INTERVAL      = 0x01 << FILTER_CONTROL_INTERVAL_BITS;
const uint8_t   FILTER_CUTOFF_THROUGH_RATE   = 24;
const uint8_t   FILTER_TABLE_FRACTION_BITS   = 14;
const uint8_t   ENV_GEN_CONTROL_INTERVAL     = 0x08;
const uint16_t  ENV_GEN_LEVEL_MAX            = 0x8000;
const uint16_t  ENV_GEN_LEVEL_MAX_X_1_5      = ENV_GEN_LEVEL_MAX + (ENV_GEN_LEVEL_MAX >> 1);
const uint16_t  ENV_GEN_LEVEL_RELEASE_STEP   = 0x1600;
const uint8_t   AMP_ENV_AMT_MAX              = 240;
const uint8_t   AMP_ENV_AMT_STEP             = 16;

const uint8_t   DATA_BYTE_MAX         = 0x7F;
const uint8_t   STATUS_BYTE_INVALID   = 0x7F;
const uint8_t   DATA_BYTE_INVALID     = 0x80;
const uint8_t   STATUS_BYTE_MIN       = 0x80;
const uint8_t   NOTE_OFF              = 0x80;
const uint8_t   NOTE_ON               = 0x90;
const uint8_t   CONTROL_CHANGE        = 0xB0;
const uint8_t   PROGRAM_CHANGE        = 0xC0;
const uint8_t   PITCH_BEND            = 0xE0;
const uint8_t   SYSTEM_MESSAGE_MIN    = 0xF0;
const uint8_t   SYSTEM_EXCLUSIVE      = 0xF0;
const uint8_t   TIME_CODE             = 0xF1;
const uint8_t   SONG_POSITION         = 0xF2;
const uint8_t   SONG_SELECT           = 0xF3;
const uint8_t   TUNE_REQUEST          = 0xF6;
const uint8_t   EOX                   = 0xF7;
const uint8_t   REAL_TIME_MESSAGE_MIN = 0xF8;
const uint8_t   ACTIVE_SENSING        = 0xFE;

const uint8_t   MODULATION    = 1;
const uint8_t   EXPRESSION    = 11;

const uint8_t   OSC_WAVE      = 24;
const uint8_t   OSC2_MIX      = 25;
const uint8_t   OSC2_COARSE   = 20;
const uint8_t   OSC2_FINE     = 21;

const uint8_t   SUB_OSC_WAVE  = 29;
const uint8_t   SUB_OSC_LEVEL = 26;
const uint8_t   PITCH_EG_AMT  = 104;
const uint8_t   PITCH_EG_TGT  = 105;

const uint8_t   FILTER_CUTOFF = 16;
const uint8_t   FILTER_RESO   = 17;
const uint8_t   CUTOFF_EG_AMT = 18;
const uint8_t   AMP_EG_ON     = 31;

const uint8_t   EG_ATTACK     = 23;
const uint8_t   EG_DECAY      = 19;
const uint8_t   EG_SUSTAIN    = 27;
const uint8_t   EG_RELEASE    = 28;

const uint8_t   LFO_WAVE      = 14;
const uint8_t   LFO_RATE      = 80;
const uint8_t   PITCH_LFO_AMT = 82;
const uint8_t   CO_LFO_AMT    = 83;

const uint8_t   LFO_DEPTH     = 81;
const uint8_t   LFO_RT_EG_AMT = 3;
const uint8_t   PITCH_LFO_TGT = 9;
const uint8_t   CC15          = 15;

const uint8_t   PB_RANGE      = 85;
const uint8_t   CC86          = 86;
const uint8_t   CO_EXP_AMT    = 106;
const uint8_t   AMP_EXP_AMT   = 107;

const uint8_t   PORTAMENTO    = 22;
const uint8_t   LEGATO        = 30;
const uint8_t   KEY_ASSIGN    = 87;
const uint8_t   EXP_BY_VEL    = 89;

const uint8_t   ALL_NOTES_OFF = 123;
const uint8_t   OMNI_MODE_OFF = 124;
const uint8_t   OMNI_MODE_ON  = 125;
const uint8_t   MONO_MODE_ON  = 126;
const uint8_t   POLY_MODE_ON  = 127;

const uint8_t   OSC_WAVEFORM_SAW = 0;
const uint8_t   OSC_WAVEFORM_SQ  = 127;

const uint8_t   SUB_WAVEFORM_SIN   = 0;
const uint8_t   SUB_WAVEFORM_NOISE = 64;
const uint8_t   SUB_WAVEFORM_SQ    = 127;

const uint8_t   LFO_WAVEFORM_TRI_ASYNC = 0;
const uint8_t   LFO_WAVEFORM_TRI_SYNC  = 32;
const uint8_t   LFO_WAVEFORM_SAW_DOWN  = 64;
const uint8_t   LFO_WAVEFORM_RANDOM    = 96;
const uint8_t   LFO_WAVEFORM_SQ        = 127;

const uint8_t   KEY_ASSIGN_LOW  = 0;
const uint8_t   KEY_ASSIGN_DUO  = 64;
const uint8_t   KEY_ASSIGN_HIGH = 96;
const uint8_t   KEY_ASSIGN_LAST = 127;

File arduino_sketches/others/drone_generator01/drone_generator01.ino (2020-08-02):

// Arduino Drone Sounds Generator
//
// for Garvuino + expansion card with 5 potentiometers
//
//
// There are four voices.
//
// Digital 3: Audio out 
//
// On GARVUINO v2.10: connect PIN D3 to PIN AY>L or AY>R (under the L or R) to make the audio output!
// On GARVUINO v1.09: remove the arduino out of the socket
//      Then connect PIN D3 to PIN AY>L (under the L label) and GND to the GND in J1 on Garvuino (or on top of J4)
//        in order to get the audio output!


/*

There are 4 modes, activated by switch sw1 (led blink for each change, hold switch if necessary):

== 1 ==

4 oscillators mode: sine, triangle, square and/or ramps.

You can change the pitch for each osc with knobs 1 to 4 (u1, u2, u3, u4).
You can change the oscillators with the 5th knob (u5) :

1: sine + sine + sine + sine
2: sine + sine + sine + tri
3: sine + sine + tri + tri
4: sine + tri + tri + tri
5: tri + tri + tri + tri
6: tri + tri + tri + sq
7: tri + tri + sq + sq
8: tri + sq + sq + sq
9: sq + sq + sq + sq
10: sq + sq + sq + ramp
11: sq + sq + ramp + ramp
12: sq + ramp + ramp + ramp
13: ramp + ramp + ramp + ramp
14: ramp + sq + tri + sin



== 2 ==

Same as above, but the 4th oscillator is now a noise sound.


== 3 ==

Beat mode.

Low kick generator. You can change the beat with the 4th switch, 
and the tonality and osc combinations with the others.


== 4 ==

Drum mode.

Simple drum generator. You can change the beat with the 4th switch, 
and the tonality and osc combinations with the others.




 
  */

 

// Made with "The Synth"
// http://blog.dzl.dk/


// synth.h is in the arduino_sketches/libs/garvuino/ folder
#include <synth.h>
#include "ssd1306.h"  // oled display by Alexey Dynda
#include <garvuino.h>


int switchInPin1 = 6;  

int switchInPin2 = 10; // not used
int switchInPin3 = 7;  // not used

#define LED 8          // 13 on previous shield 
byte ledStatus=0;
byte mode=0;
int modal=0;

const int KNOB_PIN_0 = 0; // set the input for the knob to analog pin 0
int knob_0 = 100; // initialisation


const int KNOB_PIN_1 = 1; // set the input for the knob to analog pin 1
int knob_1 = 100; // initialisation


const int KNOB_PIN_2 = 2; // set the input for the knob to analog pin 2
int knob_2 = 100; // initialisation


const int KNOB_PIN_3 = 3; // set the input for the knob to analog pin 3
int knob_3 = 100; // initialisation

const int KNOB_PIN_4 = 4; // set the input for the knob to analog pin 4
int knob_4 = 100; // initialisation


#define OLED 


synth edgar;        //-Make a synth


void BlinkLed(byte num)         // Basic blink function
{
    for (byte i=0;i<num;i++)
    {
        digitalWrite(LED,HIGH);
        delay(200);
        digitalWrite(LED,LOW);
        delay(200);
    }
}


void changeMode()
{
    mode++; 
    Serial.println("Mode: ");  Serial.println(mode);
      if (mode==0) {  
               BlinkLed(1); 
               }

             if (mode==1) { // rectangle
               BlinkLed(2);     
            //    edgar.setEnvelope(0,1);
            //    edgar.setEnvelope(1,1);
            //    edgar.setLength(1,82);
            //    edgar.setMod(1,64);
             //   edgar.setWave(1,SQUARE);
            //    edgar.mTrigger(1,75);    
               }
               
             if (mode==2) {  // saw
                    BlinkLed(3);           
               }
             if (mode==3) {  // saw
                     BlinkLed(4);             
               
               }
             if (mode==4) {
                 mode=-1;             
               
               }

}


void testSwitches()
{
int sensorVal = digitalRead(switchInPin1); // push button
   // push button
   if (sensorVal == HIGH) {
  // DO NOTHING
  } else {
// DO
  changeMode();
  }
}

void testRotary()
{
 if ((modal > 0 ) && (modal <= 10)) {
      edgar.setWave(0,SINE);
      edgar.setWave(1,SINE);
      edgar.setWave(2,SINE);
      edgar.setWave(3,SINE);
 }
 if ((modal > 10 ) && (modal <= 20))   {
      edgar.setWave(0,SINE);
      edgar.setWave(1,SINE);
      edgar.setWave(2,SINE);
      edgar.setWave(3,TRIANGLE);
 }
  if ((modal > 20 ) && (modal <= 30))   {
      edgar.setWave(0,SINE);
      edgar.setWave(1,SINE);
      edgar.setWave(2,TRIANGLE);
      edgar.setWave(3,TRIANGLE);
 }
   if ((modal > 30 ) && (modal <= 40))   {
      edgar.setWave(0,SINE);
      edgar.setWave(1,TRIANGLE);
      edgar.setWave(2,TRIANGLE);
      edgar.setWave(3,TRIANGLE);
 }
   if ((modal > 40 ) && (modal <= 50))   {
      edgar.setWave(0,TRIANGLE);
      edgar.setWave(1,TRIANGLE);
      edgar.setWave(2,TRIANGLE);
      edgar.setWave(3,TRIANGLE);
 }
    if ((modal > 50 ) && (modal <= 60))   {
      edgar.setWave(0,TRIANGLE);
      edgar.setWave(1,TRIANGLE);
      edgar.setWave(2,TRIANGLE);
      edgar.setWave(3,SQUARE);
 }
     if ((modal > 60 ) && (modal <= 70))   {
      edgar.setWave(0,TRIANGLE);
      edgar.setWave(1,TRIANGLE);
      edgar.setWave(2,SQUARE);
      edgar.setWave(3,SQUARE);
 }
      if ((modal > 70 ) && (modal <= 80))   {
      edgar.setWave(0,TRIANGLE);
      edgar.setWave(1,SQUARE);
      edgar.setWave(2,SQUARE);
      edgar.setWave(3,SQUARE);
 }
       if ((modal > 80 ) && (modal <= 90))   {
      edgar.setWave(0,SQUARE);
      edgar.setWave(1,SQUARE);
      edgar.setWave(2,SQUARE);
      edgar.setWave(3,SQUARE);
 }
        if ((modal > 90 ) && (modal <= 100))   {
      edgar.setWave(0,SQUARE);
      edgar.setWave(1,SQUARE);
      edgar.setWave(2,SQUARE);
      edgar.setWave(3,RAMP);
 }
        if ((modal > 100 ) && (modal <= 110))   {
      edgar.setWave(0,SQUARE);
      edgar.setWave(1,SQUARE);
      edgar.setWave(2,SQUARE);
      edgar.setWave(3,RAMP);
 }
         if ((modal > 110 ) && (modal <= 120))   {
      edgar.setWave(0,SQUARE);
      edgar.setWave(1,SQUARE);
      edgar.setWave(2,RAMP);
      edgar.setWave(3,RAMP);
 }
         if ((modal > 120 ) && (modal <= 130))   {
      edgar.setWave(0,SQUARE);
      edgar.setWave(1,RAMP);
      edgar.setWave(2,RAMP);
      edgar.setWave(3,RAMP);
 }
        if ((modal > 130 ) && (modal <= 140))   {
      edgar.setWave(0,RAMP);
      edgar.setWave(1,RAMP);
      edgar.setWave(2,RAMP);
      edgar.setWave(3,RAMP);
 }
       if ((modal > 140 ) && (modal <= 150))   {
      edgar.setWave(0,RAMP);
      edgar.setWave(1,SQUARE);
      edgar.setWave(2,TRIANGLE);
      edgar.setWave(3,SINE);
 }
}


void Kick()
{
  
 
  edgar.setWave(0,TRIANGLE); // try SQUARE for electro
  edgar.setEnvelope(0,58);
  edgar.setLength(0,45);  // 64 for electro kick
  edgar.setMod(0,21);
  
  edgar.mTrigger(0,35);

  //digitalWrite(LED,HIGH);
  
  }


void Snare()
{
    edgar.setWave(0,NOISE); //
  edgar.setEnvelope(0,10);
  edgar.setLength(0,70);  // 
  edgar.setMod(0,45);
  
  edgar.mTrigger(0,35);
  }


void HiHat()
{
// hi hat

  edgar.setWave(2,NOISE); // 
  edgar.setEnvelope(2,90);
  edgar.setLength(2,37);  //
  edgar.setMod(2,120);

  edgar.mTrigger(2,55);
  
}
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

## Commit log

2017-08-06 updated pcb
    [garvuino_09g.fzz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]
2017-08-06 adding pcb pic
2017-08-06 updated gerber
    [garvuino_09g.fzz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]
2017-08-06 adding new files (renamed)
    [garvuino_09g_contour.gm1]
2017-08-06 adding BOM
2017-08-17 adding arduino sketches adding breadboard schematics
    [garvuino_09g_breadboard_only.fzz]
2017-08-17 adding atmega8 instructions
    [atmega8_burn.fzz]
2017-08-17 updated breadboard
    [garvuino_09g_breadboard_only.fzz]
2017-08-23 adding avray files for programming the atmega8 chip adding new sample tunes
    [garvuino_09g_breadboard_only.fzz]
2017-08-23 adding correction on pcb
    [garvuino_10a.fzz]
2017-09-13 adding doc
    [atmega8_burn.fzz, garvuino_09g.fzz, garvuino_09g_breadboard_only.fzz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]
2017-09-13 adding PCB picture
2017-09-15 info on arduino sketches
2018-01-03 updating doc and manual adding sid gyro sketch
2018-01-07 adding some Tufty's beeper tunes
    [garvuino_10a.fzz]
2018-01-07 adding gyroscope module for sid sounds
2018-01-21 new PCB version, 2.10p release. Changelog: - Audio output shifted left so it will fit better on the board (thank you Yoruk!) - Capacitors moved so they will be less close to the switch button - tx pi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
    [garvuino_10p.fzz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]
2018-01-21 adding new gerber files
    [garvuino_10p_contour.gm1, garvuino_10p_copperBottom.gbl, garvuino_10p_copperTop.gtl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]
2018-01-21 adding potentiometer sketches
    [garvuino_10p.fzz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]
2018-02-08 updating main garvuino PCB, adding expansion board PCB
    [expansion_board.fzz, garvuino_10p.fzz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]
2018-03-18 adding auduino sketch for garvuino expansion board
    [expansion_board.fzz, garvuino_10a.fzz]
2019-03-18 update doc
    [expansion_board.fzz]
2019-03-29 new sketch: AY pitch + potentiometer
2019-04-07 adding garvuino lib updating the synth with user defined wavetables adding spreadsheet to create wavetables
    [garvuino_wave-table-spreadsheet.ods]
2019-04-11 adding garvuino lib
    [garvuino_wave-table-spreadsheet.ods]
2019-04-11 correcting merge for the synth
    [the_synth_midi.ino]
2019-04-12 vgm2rsf: forgot to skip PCM sample data after offset
2019-04-12 adding a sample tune from bamboo tracker
2019-04-12 vgm2rsf: handle the null data offset case fixes smspower Streets of Rage 2 vgm pack
2019-04-14 moving spreadsheet into the tools folder
    [garvuino_wave-table-spreadsheet.ods]
2019-04-21 adding bytebeat generator and some noise generators updating manual
    [bytebeat01.ino, noise_generator01.ino, noise_generator02.ino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]
2020-06-05 adding mmml instructions and code
    [atmega8_mmml.fzz]
2020-06-20 adding hardware chiptune project for arduino
2020-06-24 adding simple beep sample
